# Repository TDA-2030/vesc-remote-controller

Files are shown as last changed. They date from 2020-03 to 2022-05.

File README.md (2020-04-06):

# VESC Remote Controller

This remote controller is used to control the VESC motor controller. It can easily control the electric skateboard equipped with VESC drive.

| Branch | Build Status |
| --- | --- |
| master | Build Status |
| dev | Build Status |

# Feature
- Low-power Consumption
- Support Remote Power Control
- Real-time Data Backhaul
- Show Real-time packet loss rate
- Battery Current Monitoring
- Input Voltage Range of 12 V to 60 V
- Two LED Headlights
- Reserved UART to Connect Modules such as GPS
- Acceleration Sensor MPU6050

# Repository Structure

- **transmitter**: Transmitter code
- **receiver**: Receiver code
- **image**: pcb or schematic
- **doc**: Documentation

# how to build

Transmitter you need to use IAR IDE to compile, while Receiver uses STM32 to compile with MDK-V5

# Hardware

## Transmitter model rendering

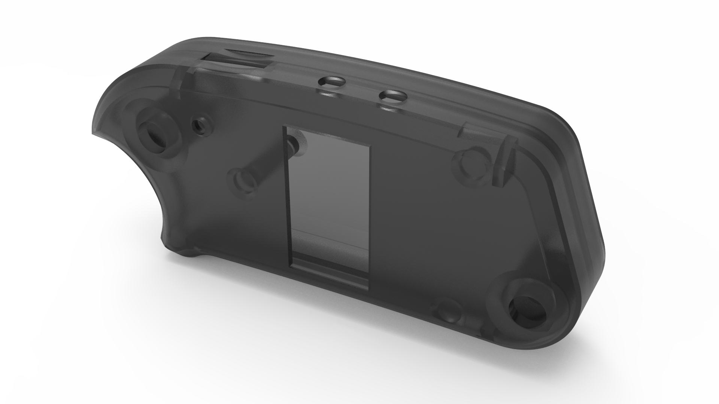
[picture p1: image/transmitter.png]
transmitter


## Receiver PCB

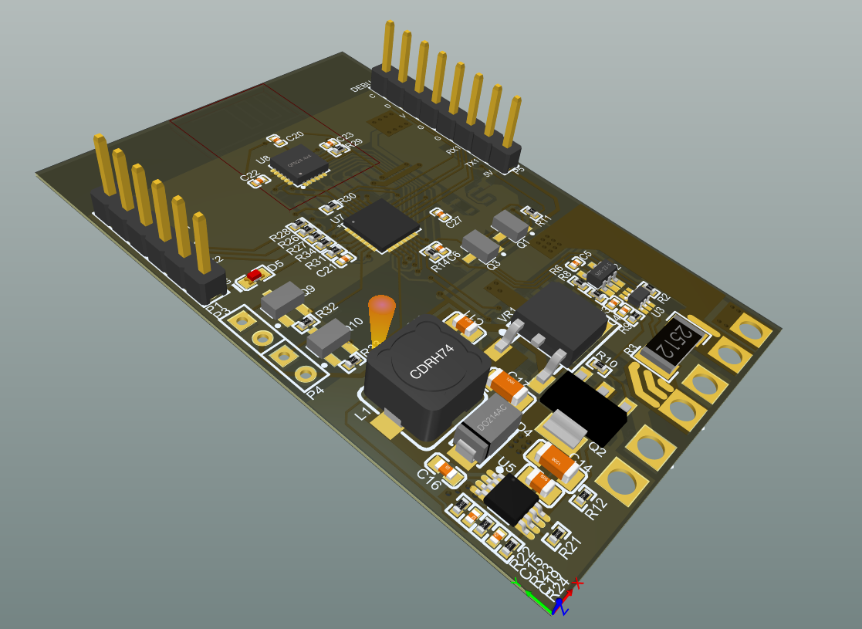
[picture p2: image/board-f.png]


## Schematic

PDF [doc/SCH-Transmitter.pdf](doc/SCH-Transmitter.pdf)

PDF [doc/SCH-Receiver.pdf](doc/SCH-Receiver.pdf)

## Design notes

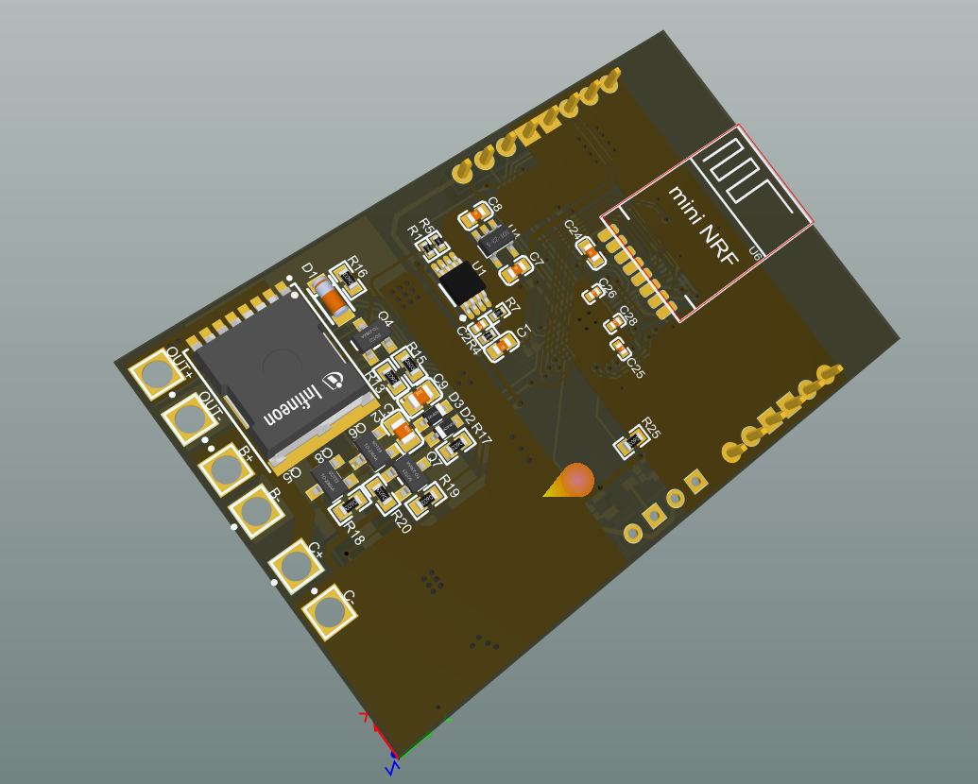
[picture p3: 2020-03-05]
image/board-b.png

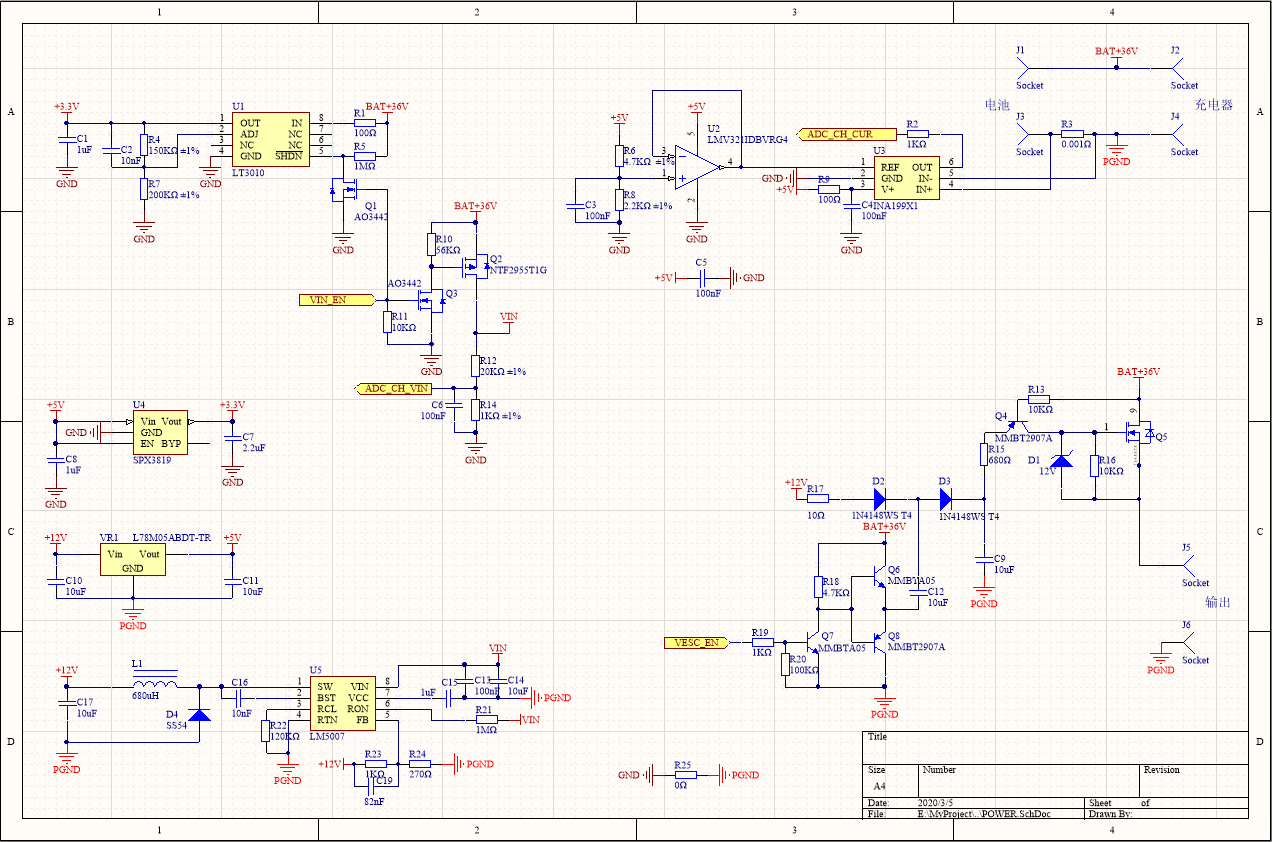
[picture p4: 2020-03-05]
image/sch-2.png

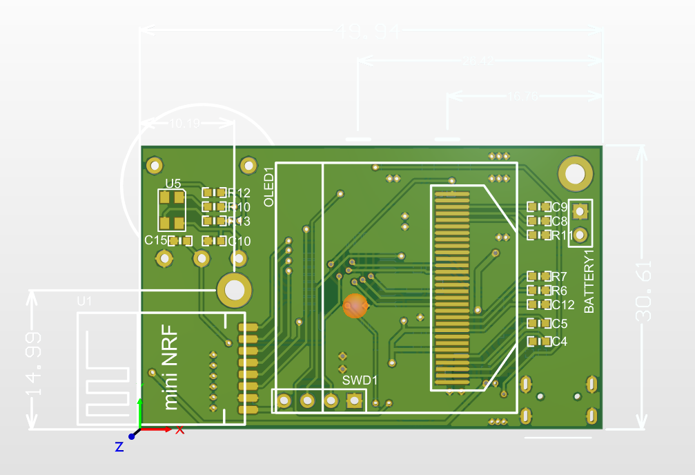
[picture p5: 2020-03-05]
image/transmitter-f.png

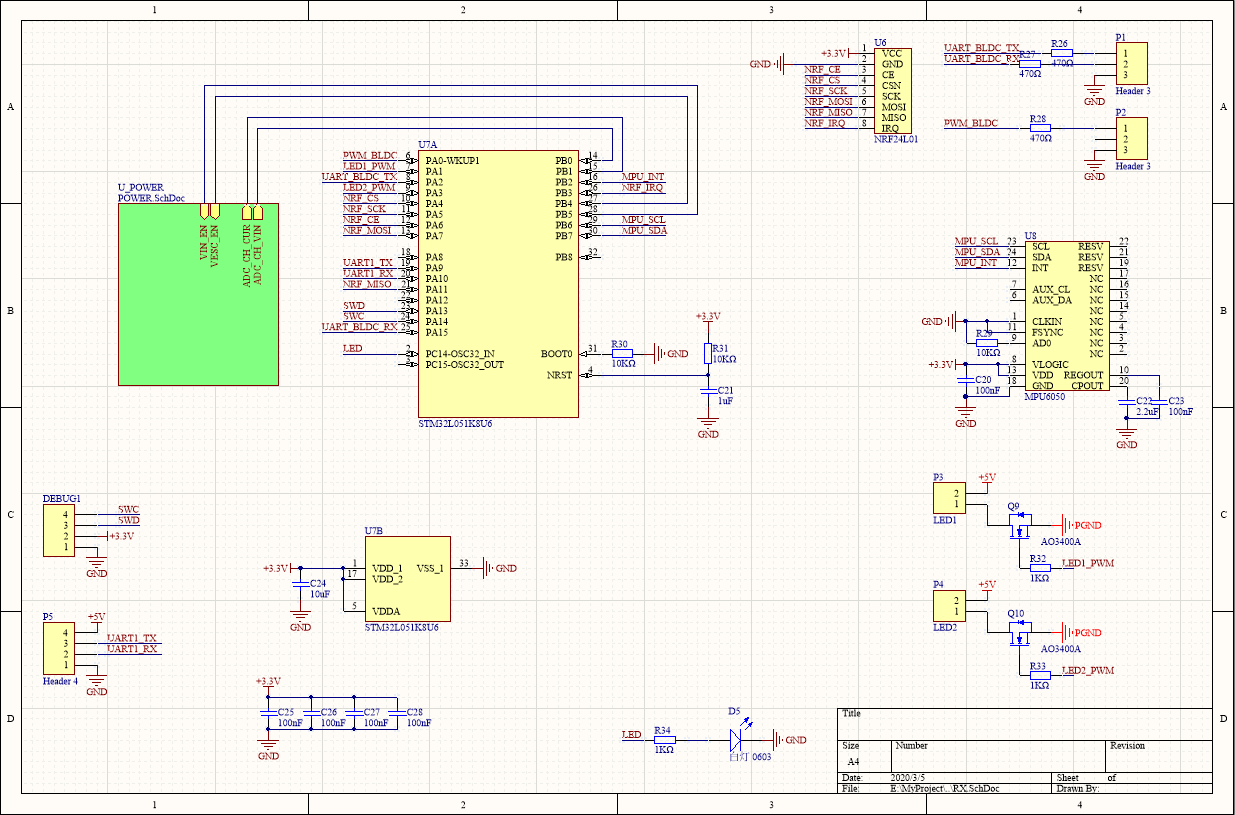
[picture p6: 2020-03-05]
image/sch-1.png

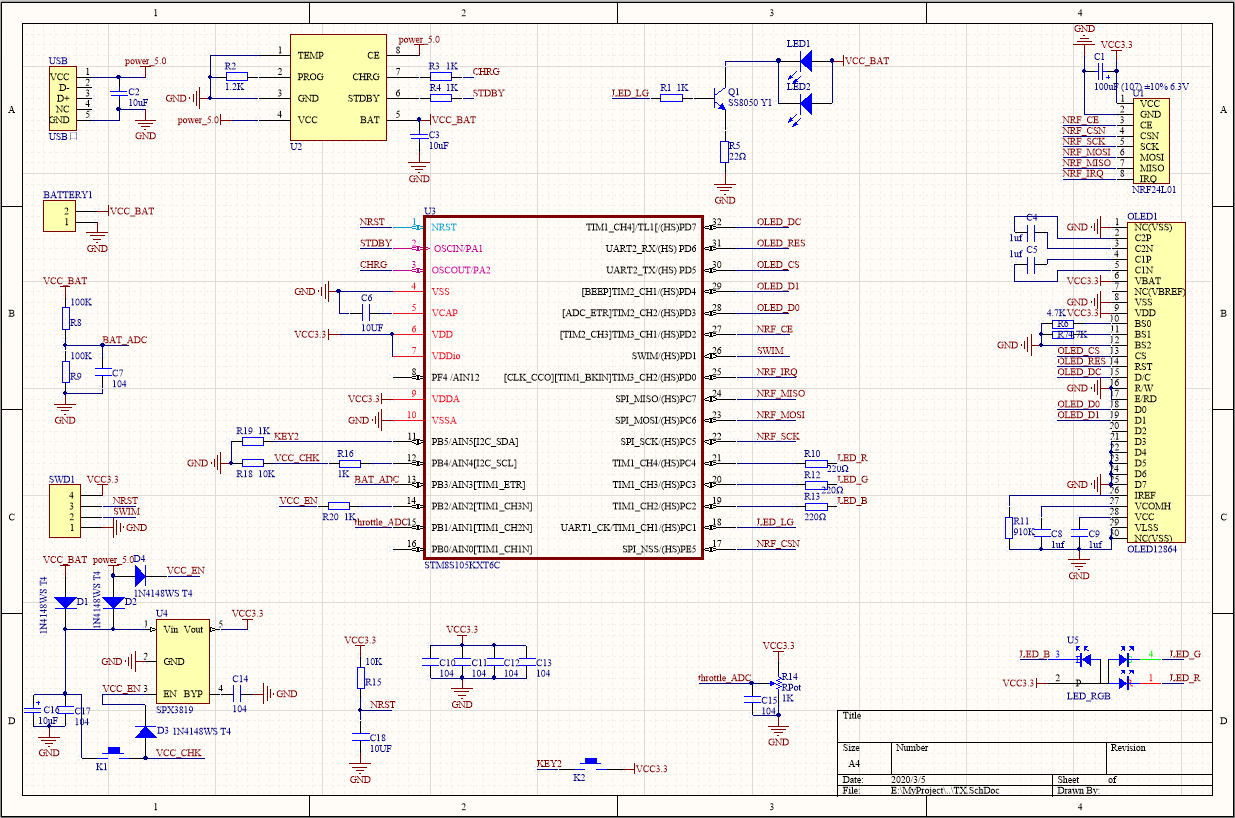
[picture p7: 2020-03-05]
image/sch-t.png

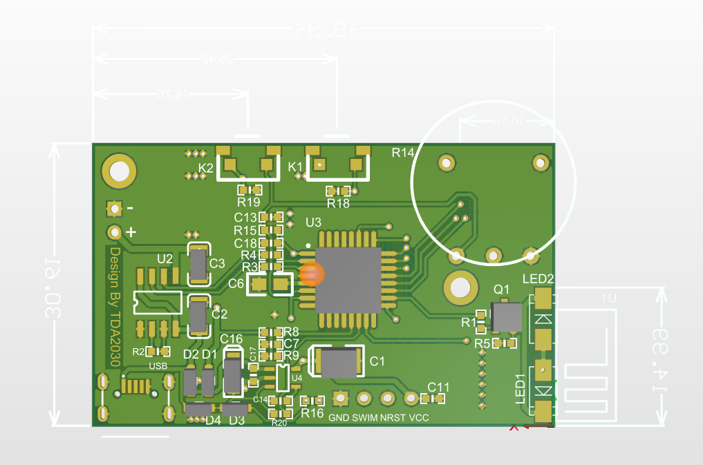
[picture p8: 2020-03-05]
image/transmitter-b.png

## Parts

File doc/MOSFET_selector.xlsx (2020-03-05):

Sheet: MOSFETs
Part Number | Status | Replacement Part | Package | Configuration | Polarity | ESD Diode | Schottky Diode | VDS (V) | VGS (±V) | ID (A) | PD (W) | RDS(ON) (mΩ max)† at VGS= |  |  |  |  |  | VGS(th) (max V) | Ciss (pF) | Coss (pF) | Crss (pF) | Qg* (nC) | Qgd (nC) | Td(on) (ns) | Td(off) (ns) | Trr (ns) | Qrr (nC)
 |  |  |  |  |  |  |  |  |  | 25°C | 25°C | 10V | 4.5V | 2.5V | 1.8V | 1.5V | 1.2V
AO3160 (http://aosmd.com/pdfs/datasheet/AO3160.pdf) | Full Production | AO3160E (http://aosmd.com/pdfs/datasheet/AO3160E.pdf) | SOT23A-3 | Single | N | No | No | 600 | 20 | 0.04 | 1.39 | 500000 | 600000 |  |  |  |  | 3.2 | 10 | 1.8 | 0.7 | 1* | 0.52 | 4 | 12.5 | 105 | 9.5 | * For bottom exposed packages, the Id and Pd are calculated at 100°C, otherwise calculated at 70°C.
AO3160E (http://aosmd.com/pdfs/datasheet/AO3160E.pdf) | Full Production |  | SOT23A-3 | Single | N | Yes | No | 600 | 20 | 0.04 | 1.39 | 500000 | 600000 |  |  |  |  | 3.2 | 9.5 | 1.7 | 0.6 | 0.9 | 0.49 |  |  | 105 | 9.5 | † Rds(on) measured at Vgs other than 10V, 4.5V, 1.8V, 1.5V, or 1.2V.
AO3162 (http://aosmd.com/pdfs/datasheet/AO3162.pdf) | Full Production |  | SOT23-3 | Single | N | No | No | 600 | 30 | 0.034 | 1.39 | 500000 |  |  |  |  |  | 4.1 | 4.2 | 0.45 | 0.05 | 0.7* | 0.05 | 13.8 | 39.2 | 105 | 9.5 | * Qg measured with Vgs at 10V. In all other cases Vgs at 4.5V.
AO3400 (http://aosmd.com/pdfs/datasheet/AO3400.pdf) | Not for New Designs | AOSS32334C (http://aosmd.com/pdfs/datasheet/AOSS32334C.pdf) | SOT23-3 | Single | N | No | No | 30 | 12 | 5.8 | 1.4 | 28 | 33 | 52 |  |  |  | 1.45 | 630 | 75 | 50 | 6 | 1.8 | 3 | 25 | 8.5 | 2.6
AO3400A (http://aosmd.com/pdfs/datasheet/AO3400A.pdf) | Not for New Designs | AOSS32334C (http://aosmd.com/pdfs/datasheet/AOSS32334C.pdf) | SOT23-3 | Single | N | No | No | 30 | 12 | 5.7 | 1.4 | 26.5 | 32 | 48 |  |  |  | 1.45 | 630 | 75 | 50 | 6 | 1.8 | 3 | 25 | 8.5 | 2.6
AO3401 (http://aosmd.com/pdfs/datasheet/AO3401.pdf) | Not for New Designs | AOSS21311C (http://aosmd.com/pdfs/datasheet/AOSS21311C.pdf) | SOT23-3 | Single | P | No | No | -30 | 12 | -4 | 1.4 | 50 | 60 | 85 |  |  |  | -1.3 | 645 | 80 | 55 | 7 | 2.5 | 6.5 | 41 | 11 | 3.5
AO3401A (http://aosmd.com/pdfs/datasheet/AO3401A.pdf) | Not for New Designs | AOSS21311C (http://aosmd.com/pdfs/datasheet/AOSS21311C.pdf) | SOT23-3 | Single | P | No | No | -30 | 12 | -4 | 1.4 | 50 | 60 | 85 |  |  |  | -1.3 | 645 | 80 | 55 | 7 | 2.5 | 6.5 | 41 | 11 | 3.5
AO3402 (http://aosmd.com/pdfs/datasheet/AO3402.pdf) | Not for New Designs | AOSS32338C (http://aosmd.com/pdfs/datasheet/AOSS32338C.pdf) | SOT23-3 | Single | N | No | No | 30 | 12 | 4 | 1.4 | 52 | 65 | 85 |  |  |  | 1.5 | 235 | 35 | 18 | 4.7 | 1.6 | 3.5 | 17.5 | 8.5 | 2.6
AO3403 (http://aosmd.com/pdfs/datasheet/AO3403.pdf) | Not for New Designs | AOSS21319C (http://aosmd.com/pdfs/datasheet/AOSS21319C.pdf) | SOT23-3 | Single | P | No | No | -30 | 12 | -2.6 | 1.4 | 115 | 150 | 200 |  |  |  | -1.4 | 260 | 37 | 20 | 2.8 | 1 | 6 | 20 | 11.5 | 4.5
AO3404 (http://aosmd.com/pdfs/datasheet/AO3404.pdf) | Obsolete |  | SOT23-3 | Single | N | No | No | 30 | 20 | 5 | 1.4 | 31 | 43 |  |  |  |  | 2.4 | 255 | 45 | 35 | 2.55 | 1.3 | 4.5 | 14.5 | 8.5 | 2.2
AO3404A (http://aosmd.com/pdfs/datasheet/AO3404A.pdf) | Not for New Designs | AOSS32334C (http://aosmd.com/pdfs/datasheet/AOSS32334C.pdf) | SOT23-3 | Single | N | No | No | 30 | 20 | 5.8 | 1.4 | 25 | 35 |  |  |  |  | 2.6 | 373 | 67 | 41 | 3.3 | 1.7 | 4.5 | 14.8 | 10.5 | 4.5
AO3406 (http://aosmd.com/pdfs/datasheet/AO3406.pdf) | Not for New Designs | AOSS32338C (http://aosmd.com/pdfs/datasheet/AOSS32338C.pdf) | SOT23-3 | Single | N | No | No | 30 | 20 | 3.6 | 1.4 | 50 | 70 |  |  |  |  | 2.5 | 170 | 35 | 23 | 2 | 1 | 4.5 | 18.5 | 7.5 | 2.5
AO3407 (http://aosmd.com/pdfs/datasheet/AO3407.pdf) | Not for New Designs | AOSS21311C (http://aosmd.com/pdfs/datasheet/AOSS21311C.pdf) | SOT23-3 | Single | P | No | No | -30 | 20 | -4.1 | 1.4 | 52 | 87 |  |  |  |  | -2.5 | 520 | 100 | 65 | 4.6 | 2.2 | 7.5 | 19 | 11 | 5.3
AO3407A (http://aosmd.com/pdfs/datasheet/AO3407A.pdf) | Not for New Designs | AOSS21311C (http://aosmd.com/pdfs/datasheet/AOSS21311C.pdf) | SOT23-3 | Single | P | No | No | -30 | 20 | -4.3 | 1.4 | 48 | 78 |  |  |  |  | -2.4 | 520 | 100 | 65 | 4.6 | 2.2 | 7.5 | 19 | 11 | 5.3
AO3409 (http://aosmd.com/pdfs/datasheet/AO3409.pdf) | Not for New Designs | AOSS21319C (http://aosmd.com/pdfs/datasheet/AOSS21319C.pdf) | SOT23-3 | Single | P | No | No | -30 | 20 | -2.6 | 1.4 | 110 | 180 |  |  |  |  | -2.4 | 197 | 42 | 26 | 2.2 | 1.1 | 7.5 | 11.8 | 11.3 | 4.4
AO3413 (http://aosmd.com/pdfs/datasheet/AO3413.pdf) | Full Production |  | SOT23-3 | Single | P | No | No | -20 | 8 | -3 | 1.4 |  | 80 | 100 | 130 |  |  | -1 | 560 | 80 | 70 | 8.5 | 2.1 | 7.2 | 53 | 37 | 27
AO3414 (http://aosmd.com/pdfs/datasheet/AO3414.pdf) | Not for New Designs | AOSS32338C (http://aosmd.com/pdfs/datasheet/AOSS32338C.pdf) | SOT23-3 | Single | N | No | No | 20 | 8 | 3 | 1.4 |  | 62 | 70 | 85 |  |  | 1 | 260 | 48 | 27 | 2.9 | 0.6 | 2.5 | 21 | 14 | 3.8
AO3415 (http://aosmd.com/pdfs/datasheet/AO3415.pdf) | Not for New Designs | AOSS21115C (http://aosmd.com/pdfs/datasheet/AOSS21115C.pdf) | SOT23-3 | Single | P | Yes | No | -20 | 8 | -4 | 1.5 |  | 41 | 53 | 65 |  |  | -0.9 | 751 | 115 | 80 | 9.3 | 2.2 | 13 | 19 | 26 | 51
AO3415A (http://www.aosmd.com/pdfs/datasheet/AO3415A.pdf) | Not for New Designs | AOSS21115C (http://aosmd.com/pdfs/datasheet/AOSS21115C.pdf) | SOT23-3 | Single | P | Yes | No | -20 | 8 | -5 | 1.5 |  | 41 | 53 | 65 |  |  | -0.9 | 751 | 115 | 80 | 9.3 | 2.2 | 13 | 19 | 26 | 51
AO3416 (http://aosmd.com/pdfs/datasheet/AO3416.pdf) | Not for New Designs | AOSS32136C (http://aosmd.com/pdfs/datasheet/AOSS32136C.pdf) | SOT23-3 | Single | N | Yes | No | 20 | 8 | 6.5 | 1.4 |  | 22 | 26 | 34 |  |  | 1.1 | 1295 | 160 | 87 | 10 | 2.6 | 280 | 3760 | 31 | 6.8
AO3418 (http://aosmd.com/pdfs/datasheet/AO3418.pdf) | Not for New Designs | AOSS32338C (http://aosmd.com/pdfs/datasheet/AOSS32338C.pdf) | SOT23-3 | Single | N | No | No | 30 | 12 | 3.8 | 1.4 | 55 | 65 | 85 |  |  |  | 1.5 | 235 | 35 | 18 | 4.7 | 1.6 | 3.5 | 17.5 | 8.5 | 2.6
AO3419 (http://aosmd.com/pdfs/datasheet/AO3419.pdf) | Full Production |  | SOT23-3 | Single | P | Yes | No | -20 | 12 | -3.5 | 1.4 | 85 | 102 | 140 |  |  |  | -1.2 | 325 | 63 | 37 | 3.1 | 1.1 | 11 | 8 | 11 | 4.3
AO3420 (http://aosmd.com/pdfs/datasheet/AO3420.pdf) | Not for New Designs | AOSS32136C (http://aosmd.com/pdfs/datasheet/AOSS32136C.pdf) | SOT23-3 | Single | N | No | No | 20 | 12 | 6 | 1.4 | 24 | 27 | 42 | 55 |  |  | 1.1 | 525 | 95 | 75 | 6 | 2 | 3 | 20 | 14 | 6
AO3421 (http://aosmd.com/pdfs/datasheet/AO3421.pdf) | Not for New Designs | AOSS21319C (http://aosmd.com/pdfs/datasheet/AOSS21319C.pdf) | SOT23-3 | Single | P | No | No | -30 | 20 | -2.6 | 1.4 | 110 | 180 |  |  |  |  | -2.4 | 197 | 42 | 26 | 2.2 | 1.1 | 7.5 | 11.8 | 11.3 | 4.4
AO3421E (http://aosmd.com/pdfs/datasheet/AO3421E.pdf) | Not for New Designs | AOSS21319C (http://aosmd.com/pdfs/datasheet/AOSS21319C.pdf) | SOT23-3 | Single | P | Yes | No | -30 | 20 | -3 | 1.4 | 95 | 160 |  |  |  |  | -2.5 | 215 | 46.5 | 27.5 | 2.2 | 1.2 | 8 | 13.5 | 9 | 16
AO3422 (http://aosmd.com/pdfs/datasheet/AO3422.pdf) | Not for New Designs |  | SOT23-3 | Single | N | No | No | 55 | 12 | 2.1 | 1.25 |  | 160 | 200 |  |  |  | 2 | 214 | 31 | 12.6 | 2.6 | 0.8 | 2.3 | 16.5 | 20 | 17
AO3423 (http://aosmd.com/pdfs/datasheet/AO3423.pdf) | Full Production |  | SOT23-3 | Single | P | Yes | No | -20 | 12 | -2 | 1.4 | 92 | 118 | 166 |  |  |  | -1.2 | 325 | 63 | 37 | 3.2 | 0.9 | 11 | 8 | 6.1 | 1.4
AO3424 (http://aosmd.com/pdfs/datasheet/AO3424.pdf) | Not for New Designs | AOSS32338C (http://aosmd.com/pdfs/datasheet/AOSS32338C.pdf) | SOT23-3 | Single | N | No | No | 30 | 12 | 3.8 | 1.4 | 55 | 65 | 85 |  |  |  | 1.5 | 235 | 35 | 18 | 4.7 | 1.6 | 3.5 | 17.5 | 8.5 | 2.6
AO3434A (http://aosmd.com/pdfs/datasheet/AO3434A.pdf) | Not for New Designs | AOSS32338C (http://aosmd.com/pdfs/datasheet/AOSS32338C.pdf) | SOT23-3 | Single | N | Yes | No | 30 | 12 | 4 | 1.4 | 52 | 60 | 78 |  |  |  | 1.5 | 245 | 35 | 20 | 2.6 | 1 | 2 | 22 | 6.5 | 7.5
AO3435 (http://aosmd.com/pdfs/datasheet/AO3435.pdf) | Not for New Designs | AOSS21115C (http://aosmd.com/pdfs/datasheet/AOSS21115C.pdf) | SOT23-3 | Single | P | No | No | -20 | 8 | -2.9 | 1 |  | 70 | 90 | 110 | 130 |  | -1 | 510 | 70 | 52 | 5.6 | 1.8 | 11 | 60 | 17 | 4
AO3442 (http://aosmd.com/pdfs/datasheet/AO3442.pdf) | Not for New Designs | AOSS62934 (http://aosmd.com/pdfs/datasheet/AOSS62934.pdf) | SOT23-3 | Single | N | No | No | 100 | 20 | 1 | 1.4 | 630 | 720 |  |  |  |  | 2.9 | 100 | 13 | 5 | 1.5 | 0.8 | 5 | 12 | 52 | 60
AO3451 (http://aosmd.com/pdfs/datasheet/AO3451.pdf) | Not for New Designs | AOSS21311C (http://aosmd.com/pdfs/datasheet/AOSS21311C.pdf) | SOT23-3 | Single | P | No | No | -30 | 12 | -4 | 1.4 | 50 | 60 | 85 |  |  |  | -1.3 | 645 | 80 | 55 | 7 | 2.5 |  |  | 11 | 3.5
AO3452 (http://aosmd.com/pdfs/datasheet/AO3452.pdf) | Not for New Designs | AOSS32338C (http://aosmd.com/pdfs/datasheet/AOSS32338C.pdf) | SOT23-3 | Single | N | No | No | 30 | 12 | 4 | 1.4 | 52 | 65 | 85 |  |  |  | 1.5 | 235 | 35 | 18 | 5 | 1.6 |  |  | 8.5 | 2.6
AO3453 (http://aosmd.com/pdfs/datasheet/AO3453.pdf) | Not for New Designs | AOSS21319C (http://aosmd.com/pdfs/datasheet/AOSS21319C.pdf) | SOT23-3 | Single | P | No | No | -30 | 12 | -2.6 | 1.4 | 115 | 150 | 200 |  |  |  | -1.4 | 260 | 37 | 20 | 3 | 1 |  |  | 11.5 | 4.5
AO3454 (http://aosmd.com/pdfs/datasheet/AO3454.pdf) | Not for New Designs | AOSS32334C (http://aosmd.com/pdfs/datasheet/AOSS32334C.pdf) | SOT23-3 | Single | N | No | No | 30 | 20 | 5.8 | 1.4 | 25 | 35 |  |  |  |  | 2.6 | 373 | 67 | 41 | 3.3 | 1.7 |  |  | 10.5 | 4.5
AO3456 (http://aosmd.com/pdfs/datasheet/AO3456.pdf) | Not for New Designs | AOSS32338C (http://aosmd.com/pdfs/datasheet/AOSS32338C.pdf) | SOT23-3 | Single | N | No | No | 30 | 20 | 3.6 | 1.4 | 50 | 70 |  |  |  |  | 2.5 | 200 | 35 | 23 | 2 | 1 |  |  | 7.5 | 2.5
AO3457 (http://aosmd.com/pdfs/datasheet/AO3457.pdf) | Not for New Designs | AOSS21311C (http://aosmd.com/pdfs/datasheet/AOSS21311C.pdf) | SOT23-3 | Single | P | No | No | 30 | 20 | -4.3 | 1.4 | 48 | 78 |  |  |  |  | -2.4 | 520 | 100 | 65 | 4.6 | 2.2 |  |  | 11 | 5.3
AO3459 (http://aosmd.com/pdfs/datasheet/AO3459.pdf) | Not for New Designs | AOSS21319C (http://aosmd.com/pdfs/datasheet/AOSS21319C.pdf) | SOT23-3 | Single | P | No | No | -30 | 20 | -2.6 | 1.4 | 110 | 180 |  |  |  |  | -2.4 | 197 | 42 | 26 | 2.2 | 1.1 |  |  | 11.3 | 4.4
AO3493 (http://aosmd.com/pdfs/datasheet/AO3493.pdf) | Not for New Designs | AOSS21115C (http://aosmd.com/pdfs/datasheet/AOSS21115C.pdf) | SOT23-3 | Single | P | No | No | -20 | 8 | -3 | 1.4 |  | 80 | 100 | 130 |  |  | -1 | 500 | 70 | 50 | 8.5 | 2.1 |  |  | 37 | 27
AO3494 (http://aosmd.com/pdfs/datasheet/AO3494.pdf) | Not for New Designs | AOSS32338C (http://aosmd.com/pdfs/datasheet/AOSS32338C.pdf) | SOT23-3 | Single | N | No | No | 20 | 8 | 3 | 1.4 |  | 62 | 70 | 85 |  |  | 1 | 260 | 48 | 27 | 3 | 0.6 |  |  | 14 | 3.8
AO3495 (http://aosmd.com/pdfs/datasheet/AO3495.pdf) | Not for New Designs | AOSS21115C (http://aosmd.com/pdfs/datasheet/AOSS21115C.pdf) | SOT23-3 | Single | P | Yes | No | -20 | 8 | -5 | 1.5 |  | 41 | 53 | 65 |  |  | -0.9 | 751 | 115 | 80 | 9.3 | 2.2 |  |  | 26 | 51
AO3498 (http://aosmd.com/pdfs/datasheet/AO3498.pdf) | Not for New Designs | AOSS32338C (http://aosmd.com/pdfs/datasheet/AOSS32338C.pdf) | SOT23-3 | Single | N | No | No | 30 | 12 | 3.8 | 1.4 | 55 | 65 | 85 |  |  |  | 1.5 | 235 | 35 | 18 | 5 | 1.6 |  |  | 8.5 | 2.6
AO3499 (http://aosmd.com/pdfs/datasheet/AO3499.pdf) | Full Production |  | SOT23-3 | Single | P | Yes | No | -20 | 12 | -3.5 | 1.4 | 85 | 102 | 140 |  |  |  | -1.2 | 325 | 63 | 37 | 3 | 1.1 |  |  | 11 | 4.3
AO4262E (http://www.aosmd.com/pdfs/datasheet/AO4262E.pdf) | Full Production |  | SO-8 | Single | N | Yes | No | 60 | 20 | 16.5 | 3.1 | 6.5 | 8.5 |  |  |  |  | 2.2 | 1650 | 520 | 52 | 15 | 6.5 | 8.5 | 50 | 19 | 60
AO4264E (http://www.aosmd.com/pdfs/datasheet/AO4264E.pdf) | Full Production |  | SO-8 | Single | N | Yes | No | 60 | 20 | 13.5 | 3.1 | 9.8 | 13.5 |  |  |  |  | 2.4 | 1100 | 300 | 28 | 7 | 3.5 | 8.5 | 50 | 18.5 | 59
AO4266E (http://www.aosmd.com/pdfs/datasheet/AO4266E.pdf) | Full Production |  | SO-8 | Single | N | No | No | 60 | 20 | 11 | 3.1 | 13.5 | 18 |  |  |  |  | 2.2 | 755 | 220 | 20 | 6.5 | 3 |  |  | 15 | 45
AO4268 (http://www.aosmd.com/res/data_sheets/AO4268.pdf) | Full Production |  | SO-8 | Single | N | No | No | 60 | 20 | 19 | 3.1 | 4.8 | 6.5 |  |  |  |  | 2.3 | 2500 | 670 | 65 | 21 | 6.5 | 6 | 22 | 22 | 80
AO4286 (http://www.aosmd.com/pdfs/datasheet/AO4286.pdf) | Full Production |  | SO-8 | Single | N | No | No | 100 | 20 | 4 | 2.5 | 68 | 92 |  |  |  |  | 2.9 | 390 | 30 | 3 | 2.8 | 1.2 | 6 | 18 | 15 | 53
AO4290A (http://www.aosmd.com/pdfs/datasheet/AO4290A.pdf) | Not for New Designs | AOSP66923 (http://www.aosmd.com/res/data_sheets/AOSP66923.pdf) | SO-8 | Single | N | No | No | 100 | 20 | 15.5 | 3.1 | 6.4 | 7.6 |  |  |  |  | 2.3 | 4525 | 345 | 22.5 | 30 | 9 |  |  | 32 | 162
AO4292E (http://www.aosmd.com/pdfs/datasheet/AO4292E.pdf) | Full Production |  | SO-8 | Single | N | Yes | No | 100 | 20 | 8 | 3.1 | 23 | 33 |  |  |  |  | 2.7 | 1200 | 93 | 6.3 | 8 | 2.5 | 7 | 20 | 20 | 80
AO4294 (http://www.aosmd.com/pdfs/datasheet/AO4294.pdf) | Not for New Designs | AOSP66923 (http://www.aosmd.com/res/data_sheets/AOSP66923.pdf) | SO-8 | Single | N | No | No | 100 | 20 | 11.5 | 3.1 | 12 | 15.5 |  |  |  |  | 2.4 | 2420 | 170 | 11 | 15 | 4 | 8 | 25 | 25 | 110
AO4294A (http://www.aosmd.com/pdfs/datasheet/AO4294A.pdf) | Not for New Designs | AOSP66923 (http://www.aosmd.com/res/data_sheets/AOSP66923.pdf) | SO-8 | Single | N | No | No | 100 | 20 | 11.5 | 3.1 | 12 | 15.5 |  |  |  |  | 2.5 | 2305 | 180 | 11.5 | 15.5 | 5 |  |  | 26.5 | 135
AO4296 (http://www.aosmd.com/pdfs/datasheet/AO4296.pdf) | Full Production | AOSP66920 (http://www.aosmd.com/res/data_sheets/AOSP66920.pdf) | SO-8 | Single | N | No | No | 100 | 20 | 13.5 | 3.1 | 8.3 | 10.6 |  |  |  |  | 2.3 | 3130 | 245 | 12.5 | 18.5 | 4.5 | 8 | 25 | 28 | 130
AO4306 (http://www.aosmd.com/pdfs/datasheet/AO4306.pdf) | Not for New Designs | AOSP36326C (http://www.aosmd.com/res/data_sheets/AOSP36326C.pdf) | SO-8 | Single | N | No | No | 30 | 20 | 13 | 3.1 | 11.5 | 15.5 |  |  |  |  | 2.5 | 760 | 125 | 70 | 6.6 | 3 | 4.4 | 17 | 7 | 8
AO4335 (http://www.aosmd.com/pdfs/datasheet/AO4335.pdf) | Not for New Designs | AOSP21321 (http://www.aosmd.com/res/data_sheets/AOSP21321.pdf) | SO-8 | Single | P | No | No | -30 | 25 | -10.5 | 3.1 | 18 | 36* |  |  |  |  | -3 | 1130 | 240 | 155 | 9.5 | 3.3 | 8.7 | 18 | 25 | 12
AO4354 (http://www.aosmd.com/pdfs/datasheet/AO4354.pdf) | Not for New Designs | AOSP32368 (http://www.aosmd.com/res/data_sheets/AOSP32368.pdf) | SO-8 | Single | N | No | No | 30 | 20 | 23 | 3.1 | 3.7 | 5.3 |  |  |  |  | 2.2 | 2010 | 898 | 124 | 17 | 8 | 7.5 | 37 | 14 | 20.3
AO4402 (http://www.aosmd.com/pdfs/datasheet/AO4402.pdf) | Not for New Designs | AO4402G (http://www.aosmd.com/res/data_sheets/AO4402G.pdf) | SO-8 | Single | N | No | No | 20 | 12 | 20 | 3.1 |  | 5.5 | 7 |  |  |  | 1.6 | 3860 | 740 | 580 | 36 | 12 | 7 | 70 | 17 | 36
AO4402G (http://www.aosmd.com/res/data_sheets/AO4402G.pdf) | Full Production |  | SO-8 | Single | N | No | No | 20 | 12 | 20 | 3.1 |  | 5.9 | 7.3 |  |  |  | 1.25 | 3300 | 485 | 370 | 31 | 8 |  |  | 17 | 30
AO4403 (http://aosmd.com/pdfs/datasheet/AO4403.pdf) | Not for New Designs | AOSP21311C (http://aosmd.com/pdfs/datasheet/AOSP21311C.pdf) | SO-8 | Single | P | No | No | -30 | 12 | -6 | 3.1 | 48 | 57 | 80 |  |  |  | -1.3 | 645 | 80 | 55 | 7 | 2.5 | 6.5 | 41 | 11 | 3.5
AO4404B (http://aosmd.com/pdfs/datasheet/AO4404B.pdf) | Not for New Designs | AOSP32320C (http://aosmd.com/pdfs/datasheet/AOSP32320C.pdf) | SO-8 | Single | N | No | No | 30 | 12 | 8.5 | 3.1 | 24 | 30 | 48 |  |  |  | 1.45 | 630 | 75 | 50 | 6 | 1.8 | 3 | 25 | 8.5 | 2.6
AO4405 (http://aosmd.com/pdfs/datasheet/AO4405.pdf) | Not for New Designs | AOSP21311C (http://aosmd.com/pdfs/datasheet/AOSP21311C.pdf) | SO-8 | Single | P | No | No | -30 | 20 | -6 | 3.1 | 50 | 85 |  |  |  |  | -2.4 | 520 | 100 | 65 | 4.6 | 2.2 | 7.5 | 19 | 11 | 5.3
AO4405E (http://aosmd.com/pdfs/datasheet/AO4405E.pdf) | Not for New Designs | AOSP21311C (http://aosmd.com/pdfs/datasheet/AOSP21311C.pdf) | SO-8 | Single | P | Yes | No | -30 | 20 | -6 | 2.5 | 45 | 80 |  |  |  |  | -1.5 | 495 | 100 | 56 | 4.2 | 2 |  |  | 9 | 13.5
AO4406A (http://aosmd.com/pdfs/datasheet/AO4406A.pdf) | Not for New Designs | AOSP36326C (http://aosmd.com/pdfs/datasheet/AOSP36326C.pdf) | SO-8 | Single | N | No | No | 30 | 20 | 13 | 3.1 | 11.5 | 15.5 |  |  |  |  | 2.5 | 760 | 125 | 70 | 6.6 | 3 | 4.4 | 17 | 7 | 8
AO4407 (http://aosmd.com/pdfs/datasheet/AO4407.pdf) | Obsolete | AOSP21307 (http://www.aosmd.com/res/data_sheets/AOSP21307.pdf) | SO-8 | Single | P | No | No | -30 | 25 | -12 | 3.1 | 14 | 30* |  |  |  |  | -2.8 | 2060 | 370 | 295 | 30* | 10 | 11 | 24 | 30 | 22
AO4407A (http://aosmd.com/pdfs/datasheet/AO4407A.pdf) | Not for New Designs | AOSP21307 (http://www.aosmd.com/res/data_sheets/AOSP21307.pdf) | SO-8 | Single | P | No | No | -30 | 25 | -12 | 3.1 | 13 | 17* |  |  |  |  | -3 | 2060 | 370 | 295 | 30* | 10 | 11 | 24 | 30 | 22
AO4411 (http://aosmd.com/pdfs/datasheet/AO4411.pdf) | Not for New Designs | AOSP21313C (http://www.aosmd.com/res/data_sheets/AOSP21313C.pdf) | SO-8 | Single | P | No | No | -30 | 20 | -8 | 3.1 | 32 | 55 |  |  |  |  | -2.4 | 760 | 140 | 95 | 6.7 | 3.2 | 8 | 17 | 15 | 9.7
AO4413 (http://aosmd.com/pdfs/datasheet/AO4413.pdf) | Obsolete | AOSP21357 (http://www.aosmd.com/res/data_sheets/AOSP21357.pdf) | SO-8 | Single | P | No | No | -30 | 25 | -15 | 3.1 | 8.5 |  |  |  |  |  | -3.5 | 2890 | 585 | 470 | 51* | 16 | 16 | 45 | 18 | 11
AO4419 (http://aosmd.com/pdfs/datasheet/AO4419.pdf) | Full Production |  | SO-8 | Single | P | No | No | -30 | 20 | -9.7 | 3.1 | 20 | 35 |  |  |  |  | -2.5 | 1040 | 180 | 125 | 9.6 | 4.6 | 10 | 26 | 11.5 | 25
AO4421 (http://aosmd.com/pdfs/datasheet/AO4421.pdf) | Full Production |  | SO-8 | Single | P | No | No | -60 | 20 | -6.2 | 3.1 | 40 | 50 |  |  |  |  | -3 | 2417 | 179 | 120 | 22.7 | 9.2 | 9.8 | 44 | 34 | 47
AO4423/L (http://aosmd.com/pdfs/datasheet/AO4423.pdf) | Obsolete | AOSP21357 (http://www.aosmd.com/res/data_sheets/AOSP21357.pdf) | SO-8 | Single | P | Yes | No | -30 | 25 | -17 | 3.1 | 7.2 |  |  |  |  |  | -2.6 | 2527 | 583 | 397 | 47* | 14 | 12 | 54 | 26.1 | 12.3
AO4425 (http://aosmd.com/pdfs/datasheet/AO4425.pdf) | Full Production |  | SO-8 | Single | P | Yes | No | -38 | 25 | -14 | 3.1 | 11 |  |  |  |  |  | -3.5 | 3800 | 560 | 350 | 63* | 16.1 | 12.4 | 97.5 | 35 | 33
AO4430 (http://aosmd.com/pdfs/datasheet/AO4430.pdf) | Not for New Designs | AOSP32368 (http://www.aosmd.com/res/data_sheets/AOSP32368.pdf) | SO-8 | Single | N | No | No | 30 | 20 | 18 | 3 | 5.5 | 7.5 |  |  |  |  | 2.5 | 6060 | 638 | 355 | 48 | 15 | 12 | 51.5 | 33.5 | 22
AO4435 (http://aosmd.com/pdfs/datasheet/AO4435.pdf) | Last Time Buy | AOSP21321 (http://www.aosmd.com/res/data_sheets/AOSP21321.pdf) | SO-8 | Single | P | No | No | -30 | 25 | -10.5 | 3.1 | 18 | 36 |  |  |  |  | -3 | 1130 | 240 | 155 | 9.5 | 3.3 | 8.7 | 18 | 25 | 12
AO4441 (http://aosmd.com/pdfs/datasheet/AO4441.pdf) | Full Production |  | SO-8 | Single | P | No | No | -60 | 20 | -4 | 3.1 | 100 | 130 |  |  |  |  | -3 | 930 | 85 | 35 | 8 | 3.2 | 8 | 31.5 | 27 | 32
AO4443 (http://aosmd.com/pdfs/datasheet/AO4443.pdf) | Full Production |  | SO-8 | Single | P | No | No | -40 | 20 | -6 | 3.1 | 42 | 63 |  |  |  |  | -2.6 | 940 | 97 | 72 | 8.4 | 4.3 | 10.3 | 39 | 17 | 11.5
AO4447A (http://aosmd.com/pdfs/datasheet/AO4447A.pdf) | Not for New Designs | AOSP21357 (http://www.aosmd.com/res/data_sheets/AOSP21357.pdf) | SO-8 | Single | P | Yes | No | -30 | 20 | -17 | 3.1 | 7 | 8 |  |  |  |  | -1.6 | 4580 | 755 | 564 | 41 | 17 | 180 | 1200 | 32 | 77
AO4449 (http://aosmd.com/pdfs/datasheet/AO4449.pdf) | Not for New Designs | AOSP21313C (http://www.aosmd.com/res/data_sheets/AOSP21313C.pdf) | SO-8 | Single | P | No | No | -30 | 20 | -7 | 3.1 | 34 | 54 |  |  |  |  | -2.4 | 760 | 140 | 95 | 6.7 | 3.2 | 8 | 17 | 15 | 9.7
AO4453 (http://www.aosmd.com/pdfs/datasheet/AO4453.pdf) | Full Production |  | SO-8 | Single | P | No | No | -12 | 8 | -9 | 2.5 |  | 19 | 26 | 36 | 50 |  | -0.9 | 1370 | 350 | 258 | 12.7 | 3.4 | 11 | 70 | 20.7 | 5.2
AO4455 (http://www.aosmd.com/pdfs/datasheet/AO4455.pdf) | Obsolete | AOSP21357 (http://www.aosmd.com/res/data_sheets/AOSP21357.pdf) | SO-8 | Single | P | No | No | -30 | 25 | -17 | 3.1 | 7.2 |  |  |  |  |  | -2.6 | 2823 | 574 | 424 | 54* | 16 | 12.5 | 49 | 22.3 | 8.8
AO4459 (http://aosmd.com/pdfs/datasheet/AO4459.pdf) | Not for New Designs | AOSP21311C (http://aosmd.com/pdfs/datasheet/AOSP21311C.pdf) | SO-8 | Single | P | No | No | -30 | 20 | -6.5 | 3.1 | 46 | 72 |  |  |  |  | -2.4 | 520 | 100 | 65 | 4.6 | 2.2 | 7.5 | 19 | 11 | 5.3
AO4466 (http://aosmd.com/pdfs/datasheet/AO4466.pdf) | Not for New Designs | AOSP32320C (http://aosmd.com/pdfs/datasheet/AOSP32320C.pdf) | SO-8 | Single | N | No | No | 30 | 20 | 10 | 3.1 | 23 | 35 |  |  |  |  | 2.6 | 373 | 67 | 41 | 3.5 | 1.6 | 4.3 | 15.8 | 6 | 6.6
AO4468 (http://aosmd.com/pdfs/datasheet/AO4468.pdf) | Not for New Designs | AOSP32320C (http://aosmd.com/pdfs/datasheet/AOSP32320C.pdf) | SO-8 | Single | N | No | No | 30 | 20 | 10.5 | 3.1 | 17 | 23 |  |  |  |  | 2.4 | 740 | 110 | 82 | 7.5 | 3 | 5 | 19 | 18 | 9
AO4476A (http://www.aosmd.com/pdfs/datasheet/AO4476A.pdf) | Not for New Designs | AOSP32314 (http://www.aosmd.com/res/data_sheets/AOSP32314.pdf) | SO-8 | Single | N | No | No | 30 | 20 | 15 | 3.1 | 7.7 | 10.8 |  |  |  |  | 2.5 | 1150 | 180 | 105 | 9.5 | 5 | 6.5 | 17 | 8.7 | 13.5
AO4480 (http://aosmd.com/pdfs/datasheet/AO4480.pdf) | Not for New Designs | AO4484 (http://www.aosmd.com/res/data_sheets/AO4484.pdf) | SO-8 | Single | N | Yes | No | 40 | 20 | 14 | 3.1 | 11.5 | 15.5 |  |  |  |  | 3 | 1600 | 320 | 100 | 10.5 | 4.8 | 3.5 | 13.2 | 31 | 33
AO4482 (http://www.aosmd.com/pdfs/datasheet/AO4482.pdf) | Full Production |  | SO-8 | Single | N | No | No | 100 | 20 | 6 | 3.1 | 37 | 42 |  |  |  |  | 2.7 | 1630 | 100 | 50 | 18 | 9 | 7 | 28 | 25 | 130
AO4484 (http://aosmd.com/pdfs/datasheet/AO4484.pdf) | Full Production |  | SO-8 | Single | N | No | No | 40 | 20 | 10 | 1.7 | 10 | 12.5 |  |  |  |  | 3 | 1500 | 215 | 135 | 13.6 | 6.4 | 6.4 | 29.6 | 30 | 19
AO4485 (http://aosmd.com/pdfs/datasheet/AO4485.pdf) | Full Production |  | SO-8 | Single | P | No | No | -40 | 20 | -10 | 1.7 | 15 | 20 |  |  |  |  | -2.5 | 2500 | 260 | 180 | 18.6 | 8.6 | 9.4 | 55 | 38 | 47
AO4486 (http://www.aosmd.com/pdfs/datasheet/AO4486.pdf) | Not for New Designs |  | SO-8 | Single | N | No | No | 100 | 20 | 4.2 | 3.1 | 79 | 90 |  |  |  |  | 2.7 | 778 | 55 | 24 | 8.1 | 4.1 | 6 | 21 | 21 | 94
AO4492 (http://www.aosmd.com/pdfs/datasheet/AO4492L.pdf) | Not for New Designs | AOSP32314 (http://www.aosmd.com/res/data_sheets/AOSP32314.pdf) | SO-8 | Single | N | No | No | 30 | 20 | 14 | 3.1 | 9.5 | 14 |  |  |  |  | 2.2 | 770 | 240 | 77 | 7.1 | 3.1 | 5 | 18 | 11 | 23
AO4494 (http://aosmd.com/pdfs/datasheet/AO4494.pdf) | Obsolete | AOSP32314 (http://www.aosmd.com/res/data_sheets/AOSP32314.pdf) | SO-8 | Single | N | No | No | 30 | 20 | 18 | 3.1 | 6.5 | 9.5 |  |  |  |  | 2.5 | 1590 | 240 | 145 | 15 | 7.8 | 6.7 | 22.5 | 28 | 24
AO4496 (http://aosmd.com/pdfs/datasheet/AO4496.pdf) | Not for New Designs | AOSP32320C (http://aosmd.com/pdfs/datasheet/AOSP32320C.pdf) | SO-8 | Single | N | No | No | 30 | 20 | 10 | 3.1 | 19.5 | 26 |  |  |  |  | 2.5 | 550 | 110 | 55 | 4.6 | 2.2 | 5 | 24 | 22 | 14
AO4498 (http://aosmd.com/pdfs/datasheet/AO4498.pdf) | Not for New Designs | AOSP32368 (http://www.aosmd.com/res/data_sheets/AOSP32368.pdf) | SO-8 | Single | N | No | No | 30 | 20 | 18 | 3.1 | 5.5 | 7.5 |  |  |  |  | 2.5 | 1910 | 316 | 227 | 18 | 11 | 8.1 | 29 | 14 | 40
AO4566 (http://aosmd.com/pdfs/datasheet/AO4566.pdf) | Not for New Designs | AOSP36326C (http://aosmd.com/pdfs/datasheet/AOSP36326C.pdf) | SO-8 | Single | N | No | No | 30 | 20 | 12 | 2.5 | 11 | 17 |  |  |  |  | 2.3 | 542 | 233 | 31 | 4.3 | 1.7 | 4 | 18 | 9.7 | 11.5
AO4576 (http://aosmd.com/pdfs/datasheet/AO4576.pdf) | Full Production |  | SO-8 | Single | N | No | No | 30 | 20 | 20 | 3.1 | 5.8 | 9.8 |  |  |  |  | 2.2 | 1037 | 441 | 61 | 6.8 | 3.6 | 5.5 | 18 | 12.7 | 17.2
AO4606 (http://aosmd.com/pdfs/datasheet/AO4606.pdf) | Full Production |  | SO-8 | Complementary | N | No | No | 30 | 20 | 6 | 2 | 30 | 42 |  |  |  |  | 2.4 | 255 | 45 | 35 | 2.55 | 1.3 | 4.5 | 14.5 | 8.5 | 2.2
AO4606 (http://aosmd.com/pdfs/datasheet/AO4606.pdf) | Full Production |  | SO-8 | Complementary | P | No | No | -30 | 20 | -6.5 | 2 | 28 | 44 |  |  |  |  | -2.4 | 760 | 140 | 95 | 6.7 | 3.2 | 8 | 17 | 15 | 9.7
AO4611 (http://aosmd.com/pdfs/datasheet/AO4611.pdf) | Not for New Designs |  | SO-8 | Complementary | N | No | No | 60 | 20 | 6.3 | 2 | 25 | 30 |  |  |  |  | 3 | 1920 | 155 | 116 | 24.2 | 14.4 | 7.6 | 28.9 | 33.2 | 43
AO4611 (http://aosmd.com/pdfs/datasheet/AO4611.pdf) | Not for New Designs |  | SO-8 | Complementary | P | No | No | -60 | 20 | -4.9 | 2 | 42 | 52 |  |  |  |  | -3 | 2417 | 179 | 120 | 22.8 | 9.6 | 9.8 | 44 | 32 | 42
AO4612 (http://aosmd.com/pdfs/datasheet/AO4612.pdf) | Full Production |  | SO-8 | Complementary | N | No | No | 60 | 20 | 4.5 | 2 | 56 | 77 |  |  |  |  | 3 | 450 | 60 | 25 | 4.3 | 2.2 | 4.7 | 15.7 | 27.5 | 32
AO4612 (http://aosmd.com/pdfs/datasheet/AO4612.pdf) | Full Production |  | SO-8 | Complementary | P | No | No | -60 | 20 | -3.2 | 2 | 105 | 135 |  |  |  |  | -3 | 930 | 85 | 35 | 8 | 3.2 | 8 | 31.5 | 27 | 32
AO4614B (http://aosmd.com/pdfs/datasheet/AO4614B.pdf) | Full Production |  | SO-8 | Complementary | N | No | No | 40 | 20 | 6 | 2 | 30 | 38 |  |  |  |  | 3 | 516 | 82 | 43 | 4.3 | 1.4 | 6.4 | 16.2 | 18 | 10
AO4614B (http://aosmd.com/pdfs/datasheet/AO4614B.pdf) | Full Production |  | SO-8 | Complementary | P | No | No | -40 | 20 | -5 | 2 | 45 | 63 |  |  |  |  | -3 | 940 | 97 | 72 | 7.9 | 3.2 | 6.2 | 44.8 | 21 | 14
AO4616 (http://aosmd.com/pdfs/datasheet/AO4616.pdf) | Full Production |  | SO-8 | Complementary | N | No | No | 30 | 20 | 8.5 | 2 | 20 | 28 |  |  |  |  | 2.4 | 740 | 110 | 82 | 7.5 | 3 | 5 | 19 | 8 | 18
AO4616 (http://aosmd.com/pdfs/datasheet/AO4616.pdf) | Full Production |  | SO-8 | Complementary | P | No | No | -30 | 20 | -7 | 2 | 22 | 40 |  |  |  |  | -2.5 | 1040 | 180 | 125 | 9.6 | 4.6 | 10 | 25 | 11.5 | 25
AO4620 (http://aosmd.com/pdfs/datasheet/AO4620.pdf) | Full Production |  | SO-8 | Complementary | N | No | No | 30 | 20 | 7.2 | 2 | 24 | 36 |  |  |  |  | 2.6 | 373 | 67 | 41 | 3.5 | 1.7 | 4.5 | 14.9 | 10.5 | 4.5
AO4620 (http://aosmd.com/pdfs/datasheet/AO4620.pdf) | Full Production |  | SO-8 | Complementary | P | No | No | -30 | 20 | -5.3 | 2 | 32 | 55 |  |  |  |  | -2.4 | 760 | 140 | 95 | 6.7 | 3.2 | 8 | 17 | 15 | 9.7
AO4627 (http://aosmd.com/pdfs/datasheet/AO4627.pdf) | Full Production |  | SO-8 | Complementary | N | No | No | 30 | 20 | 4.5 | 2 | 50 | 68 |  |  |  |  | 2.5 | 170 | 35 | 23 | 2 | 1 | 4.5 | 18.5 | 7.5 | 2.5
AO4627 (http://aosmd.com/pdfs/datasheet/AO4627.pdf) | Full Production |  | SO-8 | Complementary | P | No | No | -30 | 20 | -3.5 | 2 | 100 | 165 |  |  |  |  | -2.4 | 197 | 42 | 26 | 2.2 | 1.1 | 7.5 | 11.8 | 11.3 | 4.4
AO4629 (http://www.aosmd.com/pdfs/datasheet/AO4629.pdf) | Full Production |  | SO-8 | Complementary | N | No | No | 30 | 20 | 6 | 2 | 30 | 42 |  |  |  |  | 2.4 | 250 | 45 | 35 | 2.55 | 1.3 | 4.5 | 14.5 | 8.5 | 2.2
AO4629 (http://www.aosmd.com/pdfs/datasheet/AO4629.pdf) | Full Production |  | SO-8 | Complementary | P | No | No | -30 | 20 | -5.5 | 2 | 41 | 74 |  |  |  |  | -2.5 | 520 | 100 | 65 | 4.6 | 2.2 | 7.5 | 19 | 11 | 5.3
AO4630 (http://www.aosmd.com/pdfs/datasheet/AO4630.pdf) | Full Production |  | SO-8 | Complementary | N | No | No | 30 | 12 | 7 | 2 | 23 | 28 | 36 |  |  |  | 1.45 | 670 | 75 | 45 | 6 | 1.8 | 4.5 | 14.5 | 6.5 | 7.5
AO4630 (http://www.aosmd.com/pdfs/datasheet/AO4630.pdf) | Full Production |  | SO-8 | Complementary | P | No | No | -30 | 12 | -5 | 2 | 48 | 57 | 78 |  |  |  | -1.3 | 700 | 80 | 60 | 7 | 2.5 |  |  | 15 | 40
AO4752 (http://www.aosmd.com/pdfs/datasheet/AO4752.pdf) | Not for New Designs | AOSP36326C (http://www.aosmd.com/res/data_sheets/AOSP36326C.pdf) | SO-8 | Single | N | No | Yes | 30 | 20 | 15 | 3.1 | 8.8 | 15.5 |  |  |  |  | 2.5 | 605 | 275 | 36.5 | 5.5 | 2.6 | 5 | 17 | 11.5 | 12.5
AO4800 (http://aosmd.com/pdfs/datasheet/AO4800.pdf) | Not for New Designs | AOSD32334C (http://aosmd.com/pdfs/datasheet/AOSD32334C.pdf) | SO-8 | Dual | N | No | No | 30 | 12 | 6.9 | 2 | 27 | 32 | 50 |  |  |  | 1.5 | 630 | 75 | 50 | 6 | 1.8 | 3 | 25 | 8.5 | 2.6
AO4800B (http://aosmd.com/pdfs/datasheet/AO4800B.pdf) | Not for New Designs | AOSD32334C (http://aosmd.com/pdfs/datasheet/AOSD32334C.pdf) | SO-8 | Dual | N | No | No | 30 | 12 | 6.9 | 2 | 27 | 32 | 50 |  |  |  | 1.5 | 630 | 75 | 50 | 6 | 1.8 | 3 | 25 | 8.5 | 2.6
AO4801 (http://aosmd.com/pdfs/datasheet/AO4801.pdf) | Not for New Designs | AOSD21311C (http://aosmd.com/pdfs/datasheet/AOSD21311C.pdf) | SO-8 | Dual | P | No | No | -30 | 12 | -5 | 2 | 48 | 57 | 80 |  |  |  | -1.3 | 645 | 80 | 55 | 7 | 2.5 | 6.5 | 41 | 11 | 3.5
AO4801A (http://aosmd.com/pdfs/datasheet/AO4801A.pdf) | Not for New Designs | AOSD21311C (http://aosmd.com/pdfs/datasheet/AOSD21311C.pdf) | SO-8 | Dual | P | No | No | -30 | 12 | -5 | 2 | 48 | 57 | 80 |  |  |  | -1.3 | 645 | 80 | 55 | 7 | 2.5 | 6.5 | 41 | 11 | 3.5
AO4803 (http://aosmd.com/pdfs/datasheet/AO4803.pdf) | Not for New Designs | AOSD21311C (http://aosmd.com/pdfs/datasheet/AOSD21311C.pdf) | SO-8 | Dual | P | No | No | -30 | 20 | -5 | 2 | 52 | 87 |  |  |  |  | -2.4 | 520 | 100 | 65 | 4.6 | 2.2 | 7.5 | 19 | 11 | 5.3
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

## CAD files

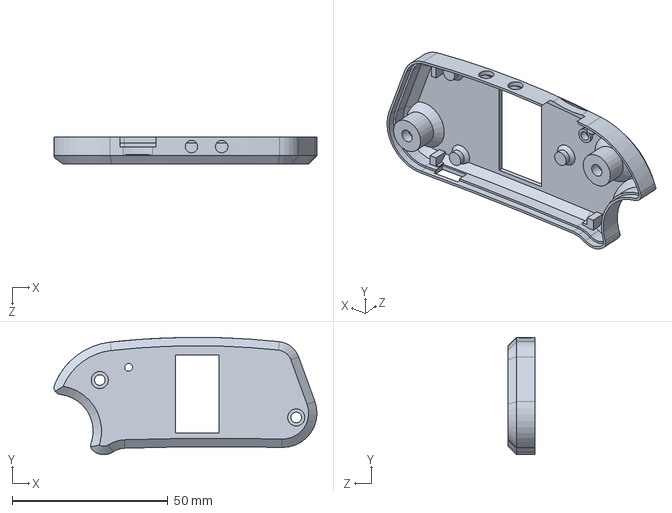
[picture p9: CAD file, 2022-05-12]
3d-models/遥控器前壳.SLDPRT
84.4 x 37.6 x 8.70 mm

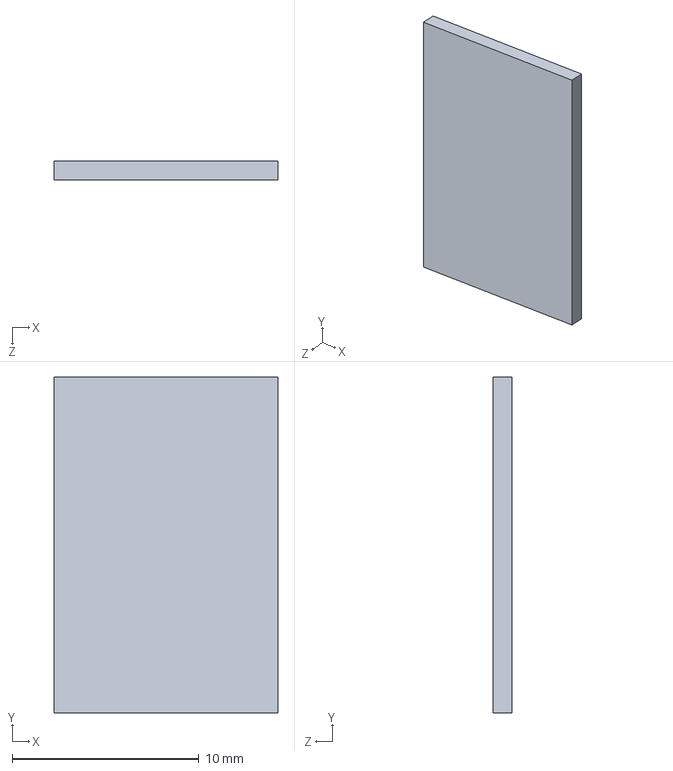
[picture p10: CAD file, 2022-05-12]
mininrf/零件1.STEP
12.0 x 18.0 x 1.00 mm

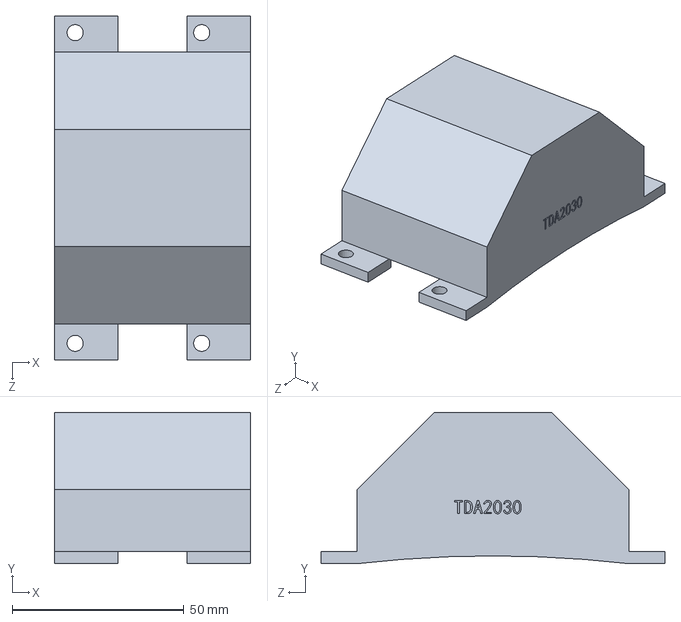
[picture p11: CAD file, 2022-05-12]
3d-models/bjm.SLDPRT
57.0 x 44.0 x 100.0 mm

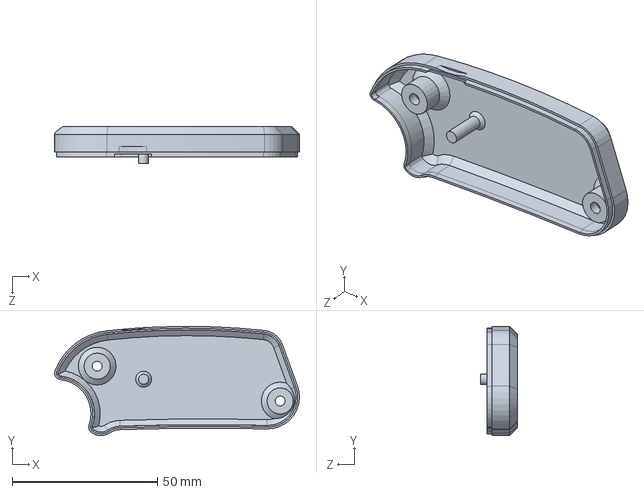
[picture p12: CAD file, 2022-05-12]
3d-models/遥控器后壳.SLDPRT
84.4 x 37.6 x 12.7 mm

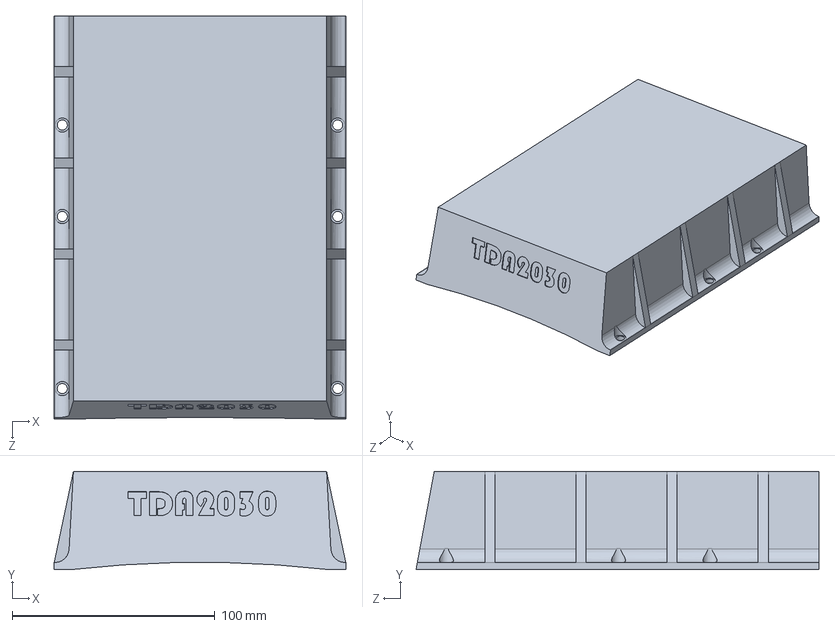
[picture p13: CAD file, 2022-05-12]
3d-models/电池盒.SLDPRT
144.0 x 48.5 x 199.0 mm

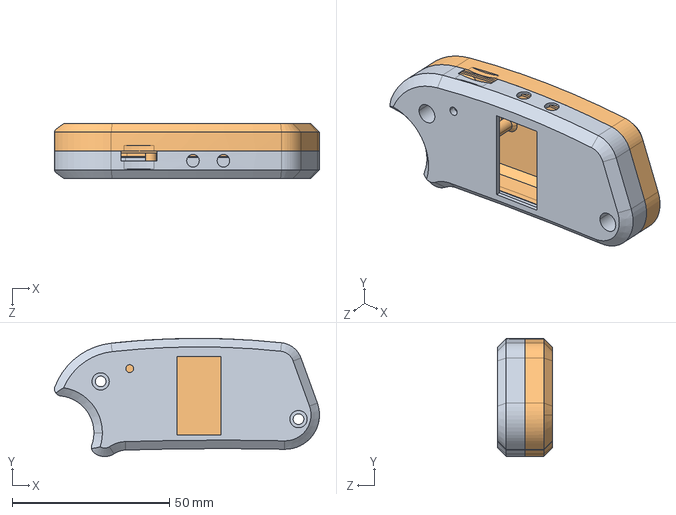
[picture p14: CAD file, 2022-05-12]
3d-models/装配体1.STEP
84.4 x 37.6 x 17.4 mm
猀諷んヶ褲
遥控器后壳

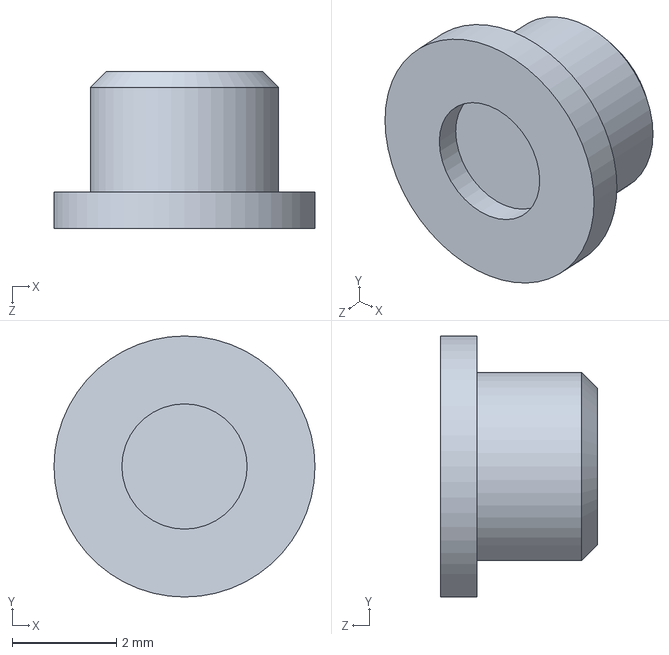
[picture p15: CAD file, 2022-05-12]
3d-models/遥控器按钮.SLDPRT
5.00 x 5.00 x 3.00 mm

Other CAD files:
mininrf/2.NRF24L01程序/NRF24L01程序/双按键测试程序/out/MAIN.obj
mininrf/2.NRF24L01程序/NRF24L01程序/双按键测试程序/out/delay.obj
mininrf/2.NRF24L01程序/NRF24L01程序/双按键测试程序/out/UART.obj
mininrf/2.NRF24L01程序/NRF24L01程序/双按键测试程序/out/nrf24l01p.obj
3d-models/装配体1.SLDASM
mininrf/零件1.SLDPRT

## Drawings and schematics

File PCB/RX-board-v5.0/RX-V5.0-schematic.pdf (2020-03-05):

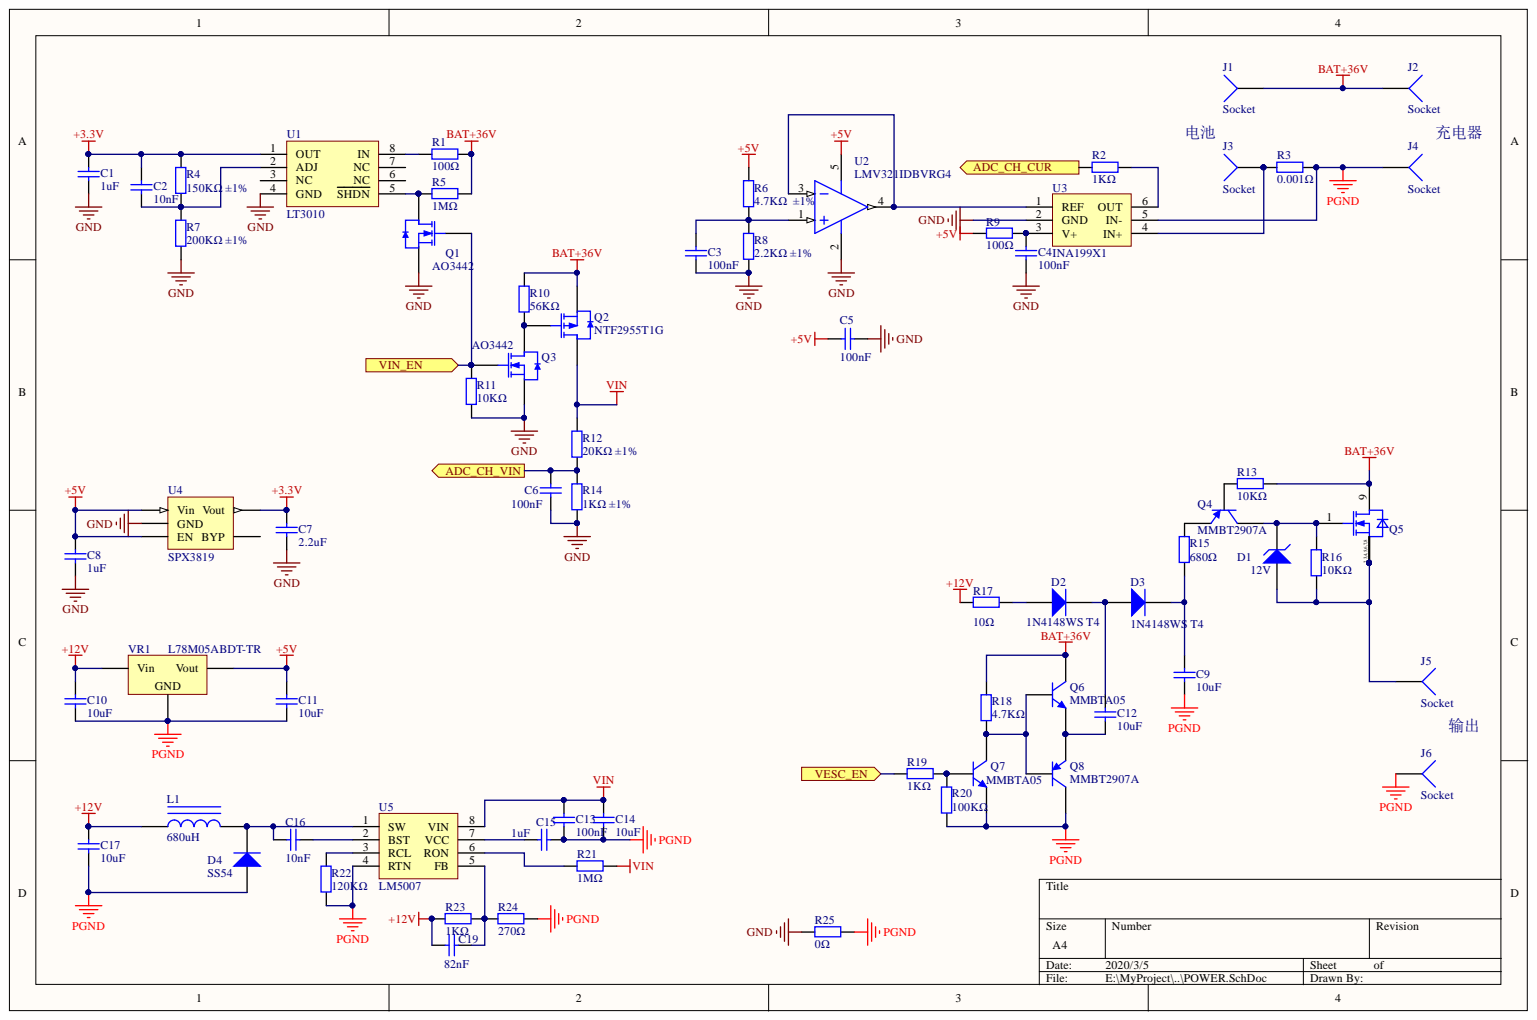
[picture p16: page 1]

C13
100nF

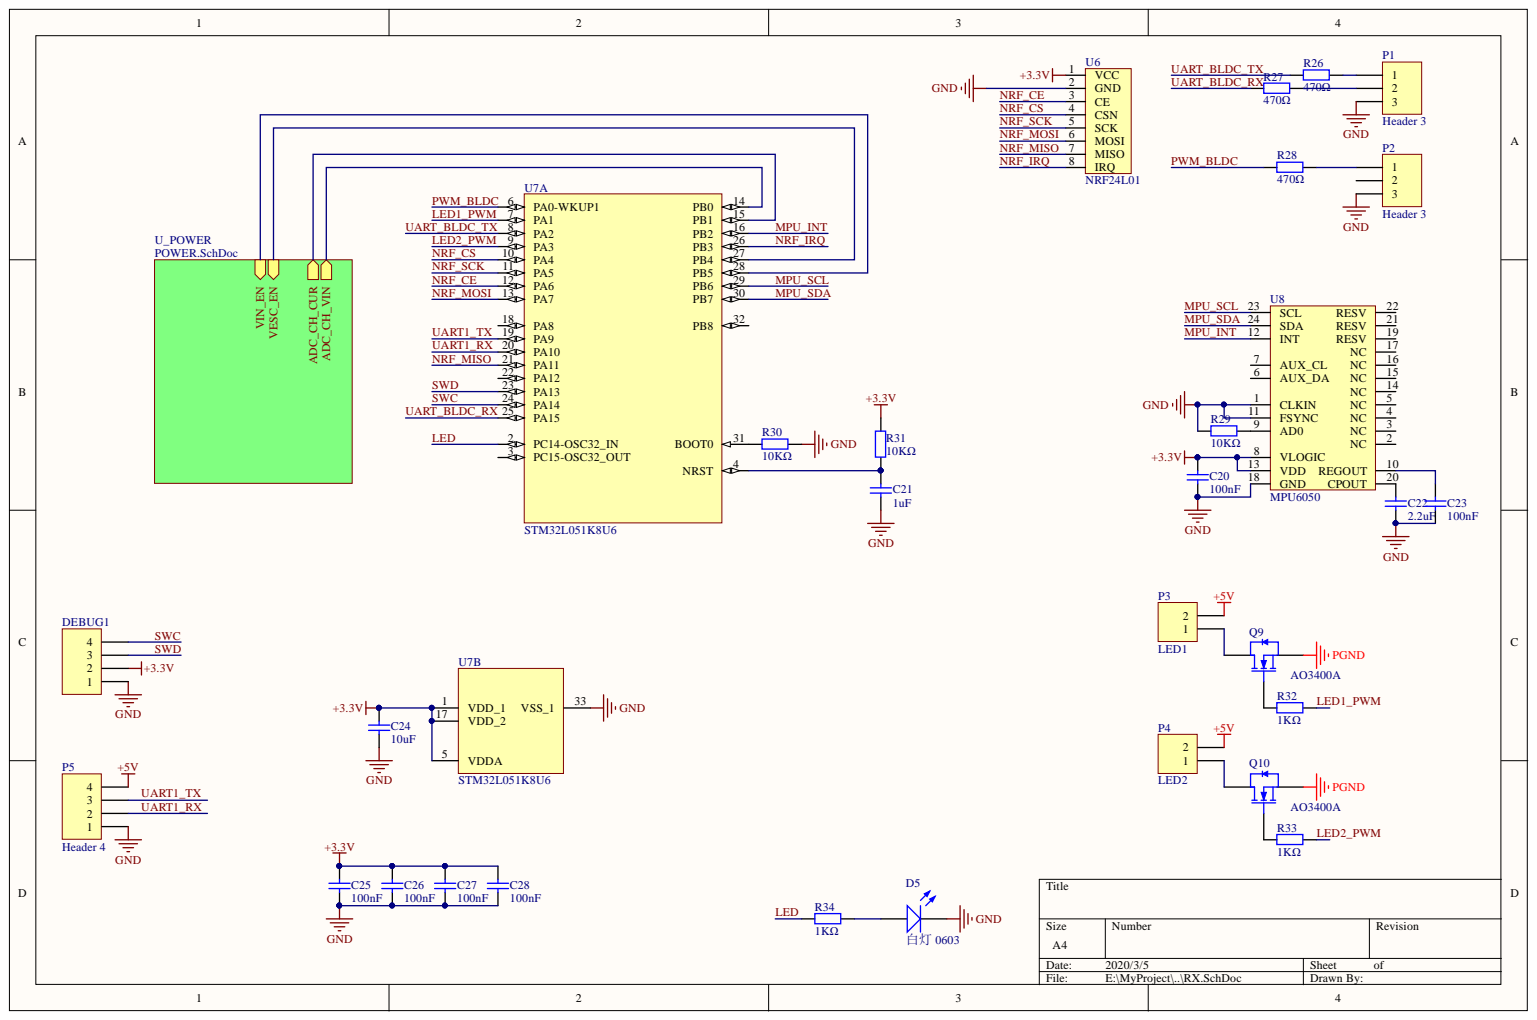
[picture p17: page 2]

NRF_CE 1 2 | PA 5 PB5 PA 6 PB6 PA 7 PB7 PA 8 PB8 PA 9 PA 1 0 PA 1 1 PA 1 2 PA 1 3 PA 1 4 PA 1 5 PC1 4-OSC3 2 _IN BO O T 0 PC1 5-OSC3 2 _ O U T NRST

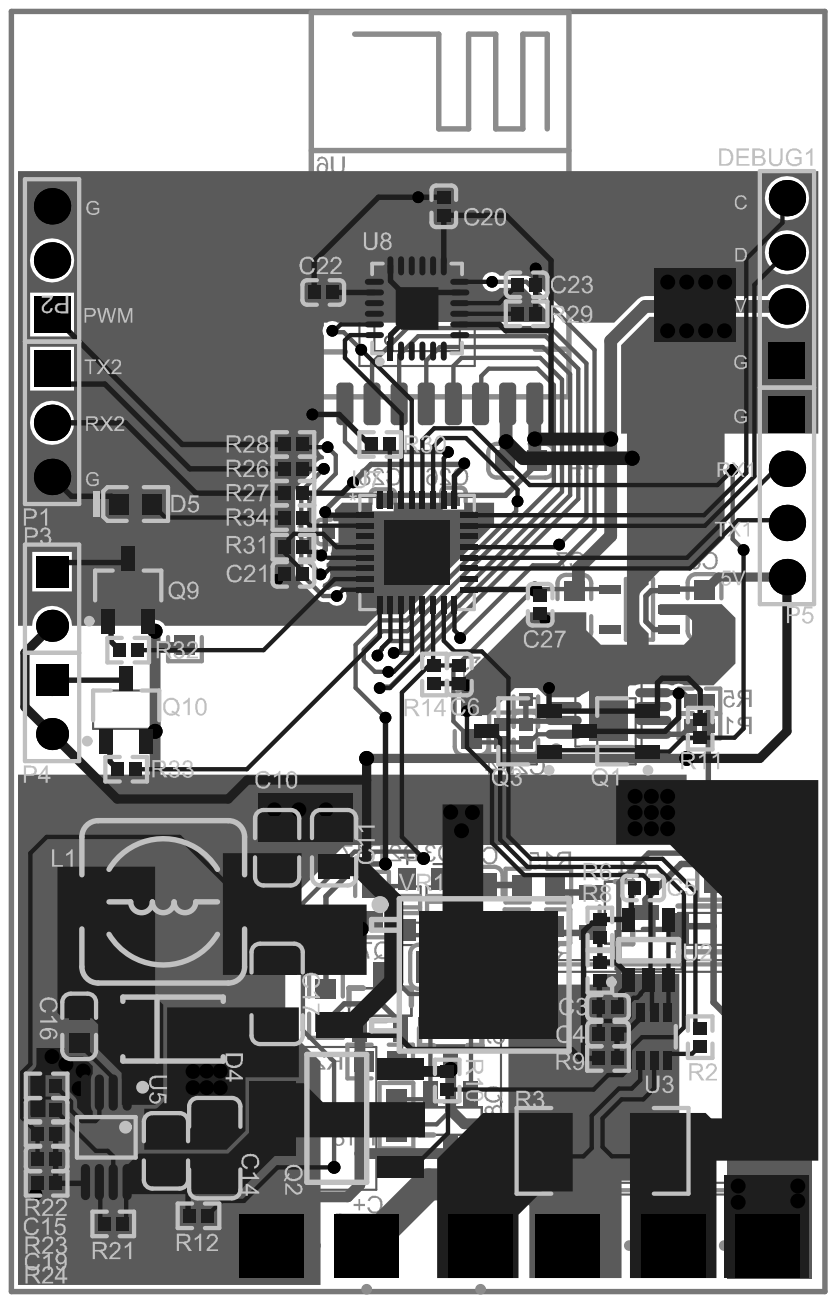
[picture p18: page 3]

# Board Stack Report

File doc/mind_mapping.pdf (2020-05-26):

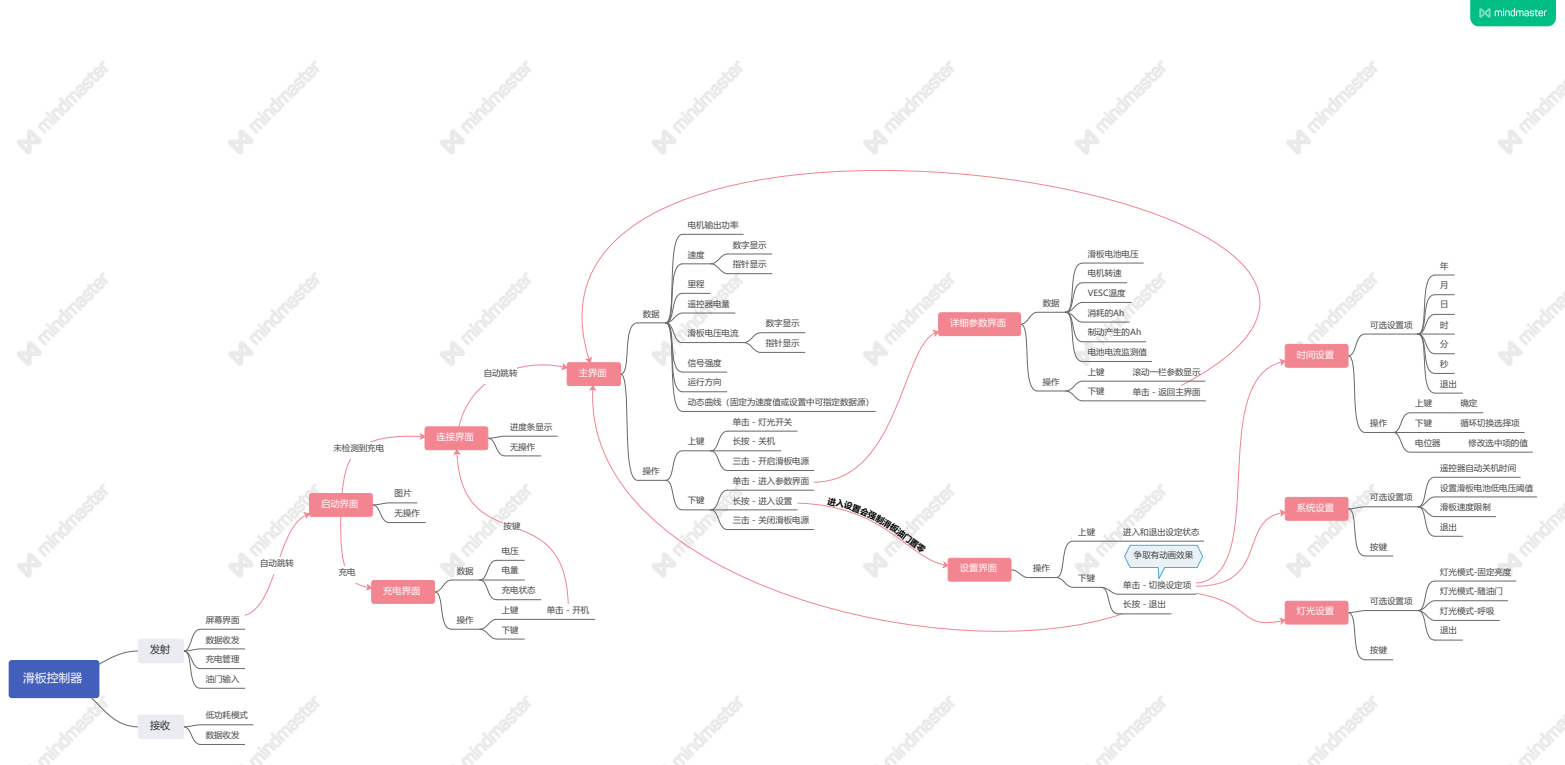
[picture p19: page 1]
自动跳转; 未检测到充电; 进入设置会强制滑板油门置零; 争取有动画效果; 滑板控制器; 屏幕界面; 数据收发; 充电管理; 油门输入; 低功耗模式; 主界面; 充电界面; 启动界面; 连接界面; 详细参数界面; 设置界面; 遥控器电量; 滑板电压电流; 信号强度; 单击 - 灯光开关; 单击 - 进入参数界面; 长按 - 进入设置; 充电状态; 进度条显示; 滑板电池电压; 电机输出功率; 电机转速; VESC温度; 运行方向; 三击 - 开启滑板电源; 无操作; 消耗的Ah; 制动产生的Ah; 电池电流监测值; 单击 - 返回主界面; 单击 - 切换设定项; 进入和退出设定状态; 时间设置; 系统设置; 灯光设置; 年月日时分秒; 遥控器自动关机时间; 灯光模式; -固定亮度; -随油门; 设置滑板电池低电压阈值; 数字显示; 指针显示; 可选设置项; 循环切换选择项; 滚动一栏参数显示; 动态曲线（固定为速度值或设置中可指定数据源）; 电位器; 修改选中项的值; 滑板速度限制

三击 - 关闭滑板电源 无操作

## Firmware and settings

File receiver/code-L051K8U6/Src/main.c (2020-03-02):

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

/* Includes ------------------------------------------------------------------*/
#include "main.h"
#include "adc.h"
#include "dma.h"
#include "i2c.h"
#include "rtc.h"
#include "spi.h"
#include "tim.h"
#include "usart.h"
#include "gpio.h"

/* USER CODE BEGIN Includes */
#include "comm_uart.h"
#include "bldc_interface.h"

#include "24l01.h"
#include "control.h"

#include "stmflash.h"

/* USER CODE END Includes */

/* USER CODE BEGIN PM */
#define SETTINGS_ADDR DATA_EEPROM_BASE
#define FLASH_CHECK (0x12345678)   //检验值
/* USER CODE END PM */


void SystemClock_Config(void);
/* USER CODE BEGIN 0 */

Setting_TypeDef setting={0};
sample_TypeDef SampleData={0};
System_TypeDef system={0};


//延时nus
//nus为要延时的us数.		    								   
void delay_us(uint32_t nus)
{		
	uint32_t t;
	while(nus--)
	{
		t=2;
		while(t--){}
		
	}
}


/** 
* @brief  : systick中断回调函数，1ms调用一次
* @param  : 
* @param  : 
* @return : 
*/
void HAL_SYSTICK_Callback(void)
{
	bldc_packet_timer();
	
}

/**
  * @brief  Wake Up Timer callback.
  * @param  hrtc RTC handle
  * @retval None
  */
void HAL_RTCEx_WakeUpTimerEventCallback(RTC_HandleTypeDef *hrtc)
{
	
}

/**
  * @brief  Conversion complete callback in non-blocking mode.
  * @param  hadc ADC handle
  * @retval None
  */
void HAL_ADC_ConvCpltCallback(ADC_HandleTypeDef* hadc)
{
	
}



//系统进入待机模式
void Sys_Enter_Standby(void)
{			 
	
	RF24L01_Set_Mode(MODE_PD);//设置为掉电模式
	LL_GPIO_ResetOutputPin(IO_VIN_EN_GPIO_Port, IO_VIN_EN_Pin);
//	hal_gpio_;	//复位所有IO口	
//	RCC_APB1PeriphClockCmd(RCC_APB1Periph_PWR, ENABLE);	//使能PWR外设时钟
	HAL_PWREx_EnableUltraLowPower();
	HAL_PWR_EnterSTOPMode(PWR_LOWPOWERREGULATOR_ON, PWR_STOPENTRY_WFI);	 
}

#define ROUND_UP(x, align) (((int) (x) + (align - 1)) & ~(align - 1))
/** 
* @brief  : flash参数读取
* @param  : 
* @param  : 
* @return : 
*/
int8_t setting_read(void)
{
	static uint32_t nword;
	nword = sizeof(Setting_TypeDef);
	nword = ROUND_UP(sizeof(Setting_TypeDef), 4)>>2;
	
	STMFLASH_Read(SETTINGS_ADDR,(uint32_t*)&setting,nword);
	if(setting.check != FLASH_CHECK)
	{
		setting.check = FLASH_CHECK;
		setting.adc_offset_crg_cur = 0;
		setting.adc_offset_dcrg_cur = 0;
		setting.adc_offset_vol = 0;
		
		STMFLASH_Write(SETTINGS_ADDR,(uint32_t*)&setting,nword);
		return -1;
	}
	return 0;
}


/** 
* @brief  : flash参数保存
* @param  : 
* @param  : 
* @return : 
*/
int8_t setting_write(void)
{
	uint32_t nword = ROUND_UP(sizeof(Setting_TypeDef), 4)>>2;
	setting.check = FLASH_CHECK;
	STMFLASH_Write(SETTINGS_ADDR,(uint32_t*)&setting,nword);
	return 0;
}



/* USER CODE END 0 */

/**
  * @brief  The application entry point.
  * @retval int
  */
int main(void)
{
  /* USER CODE BEGIN 1 */

	uint32_t time_ls=0;
	uint32_t time_50ms=0;
	uint32_t time_bldc=0;
  /* USER CODE END 1 */
  

  /* MCU Configuration--------------------------------------------------------*/

  /* Reset of all peripherals, Initializes the Flash interface and the Systick. */
  HAL_Init();

  /* Configure the system clock */
  SystemClock_Config();

  /* USER CODE BEGIN SysInit */
	MX_GPIO_Init();
	MX_DMA_Init();
	MX_I2C1_Init();
	
	MX_USART1_UART_Init();
	
	NRF24L01_Base_Init();//-- 包含SPI初始化
	while (NRF24L01_Check())
    {
        HAL_Delay(200);
		LL_GPIO_TogglePin(LED_GPIO_Port, LED_Pin);
    }
	RF24L01_Init();
    RF24L01_Set_Mode(MODE_RX);//设置为接收模式
	system.state = SYSTEM_STATE_STANDBY;
	
//	if(__HAL_PWR_GET_FLAG(PWR_FLAG_WU))
//	{
//		uint16_t t=100;
//		LL_GPIO_SetOutputPin(LED_GPIO_Port, LED_Pin);
//		while(1)
//		{
//			delay_us(100);
//			if(0 == --t)
//			{
//				LL_GPIO_ResetOutputPin(LED_GPIO_Port, LED_Pin);
//				if (HAL_RTCEx_SetWakeUpTimer_IT(&hrtc, 3500, RTC_WAKEUPCLOCK_RTCCLK_DIV16) != HAL_OK)
//				  {
//					Error_Handler();
//				  }
//				Sys_Enter_Standby();
//			}
//			if(SYSTEM_STATE_IDLE == system.state)
//			{
//				__HAL_PWR_CLEAR_FLAG(PWR_FLAG_WU);
//				HAL_RTCEx_DeactivateWakeUpTimer(&hrtc);
//				break;
//			}
//		}
//	}
	system.state = SYSTEM_STATE_IDLE;
	
  /* USER CODE END SysInit */

  /* Initialize all configured peripherals */

  /* USER CODE BEGIN 2 */
	
	hrtc.Instance = RTC;
	hrtc.Init.HourFormat = RTC_HOURFORMAT_24;
	hrtc.Init.AsynchPrediv = 127;
	hrtc.Init.SynchPrediv = 255;
	hrtc.Init.OutPut = RTC_OUTPUT_DISABLE;
	hrtc.Init.OutPutRemap = RTC_OUTPUT_REMAP_NONE;
	hrtc.Init.OutPutPolarity = RTC_OUTPUT_POLARITY_HIGH;
	hrtc.Init.OutPutType = RTC_OUTPUT_TYPE_OPENDRAIN;
	if (HAL_RTC_Init(&hrtc) != HAL_OK)
	{
		Error_Handler();
	}
  
	if(0x32F2 != HAL_RTCEx_BKUPRead(&hrtc, RTC_BKP_DR0))
	{
		MX_RTC_Init();
		HAL_RTCEx_BKUPWrite(&hrtc, RTC_BKP_DR0, 0x32F2);
	}
	
//	if(0 > setting_read())
//	{
//		while(1)
//		{
//			HAL_Delay(100);
//			LL_GPIO_TogglePin(LED_GPIO_Port, LED_Pin);
//		}
//	}setting_write();
	control_Init();
	bldc_comm_uart_init();
	MX_ADC_Init();
	
  /* USER CODE END 2 */
 
	uint8_t retry;
	uint32_t t_end;
	
	retry = 5;
	while(retry--)
	{
		bldc_interface_get_fw_version();
		t_end = HAL_GetTick() + 1000;
		while(1)
		{
			bldc_packet_process();
			if((HAL_GetTick() > t_end) || (vesc_info.fw_major>2))
			{
				break;
			}
		}
		if(vesc_info.fw_major>2)
		{
			HAL_Delay(200);
			bldc_interface_get_mcconf();
			t_end = HAL_GetTick() + 1000;
			while(1)
			{
				bldc_packet_process();
				if((HAL_GetTick() > t_end) || (vesc_info.mcconf.l_current_max != 0))
				{
					break;
				}
			}
			break;
		}
		
	}


  /* Infinite loop */
  /* USER CODE BEGIN WHILE */
	while (1)
	{
		bldc_packet_process();

		if(HAL_GetTick()>time_ls)
		{
			time_ls = HAL_GetTick()+1000;
			RTC_Get();
			LL_GPIO_TogglePin(LED_GPIO_Port, LED_Pin);
		}
		
		if(HAL_GetTick() > time_50ms)
		{
			time_50ms = HAL_GetTick()+50;
			HAL_ADC_Start_DMA(&hadc, (uint32_t*)SampleData.ADC_Value_Array, ADC_ARRAY_SIZE);
		}
		
		if(HAL_GetTick() > time_bldc)
		{
			time_bldc = HAL_GetTick()+600;
			if(system.state==SYSTEM_STATE_RUNNING)
			{
				bldc_interface_get_values();
			}
		}
		

    /* USER CODE END WHILE */

    /* USER CODE BEGIN 3 */

	}
  /* USER CODE END 3 */
}

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
/* USER CODE BEGIN 4 */

char error_message[32];

/* USER CODE END 4 */
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


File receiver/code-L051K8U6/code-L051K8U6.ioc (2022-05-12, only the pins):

Mcu.UserName=STM32L051K8Ux
PA0.Signal=S_TIM2_CH1
PA1.Signal=S_TIM2_CH2
PA10.Signal=USART1_RX
PA11.Signal=SPI1_MISO
PA13.Signal=SYS_SWDIO
PA14.Signal=SYS_SWCLK
PA15.Signal=USART2_RX
PA2.Signal=USART2_TX
PA3.Signal=S_TIM2_CH4
PA4.GPIO_Label=NRF_CS
PA4.Signal=GPIO_Output
PA5.Signal=SPI1_SCK
PA6.GPIO_Label=NRF_CE
PA6.Signal=GPIO_Output
PA7.Signal=SPI1_MOSI
PA9.Signal=USART1_TX
PB0.Signal=ADC_IN8
PB1.Signal=ADC_IN9
PB2.GPIO_Label=MPU_INT
PB2.Signal=GPXTI2
PB3.GPIO_Label=NRF_IRQ
PB3.Signal=GPXTI3
PB4.Signal=S_TIM22_CH1
PB5.GPIO_Label=IO_VIN_EN
PB5.Signal=GPIO_Output
PB6.Signal=I2C1_SCL
PB7.Signal=I2C1_SDA
PC14-OSC32_IN.GPIO_Label=LED
PC14-OSC32_IN.Signal=GPIO_Output

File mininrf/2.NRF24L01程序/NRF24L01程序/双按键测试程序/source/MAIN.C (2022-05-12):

/******************************************************************************/
/*                        -- 深圳安信可科技有限公司 --                        */
/*
//  文件名：main.c                                                              
//  说明：供客户测试模块通信使用程序                                                                  
//  编写人员：                                                                   
//  编写日期：                                                              
//  程序维护：
//  维护记录：
//
//                                                          
*/ 
// 免责声明：该程序仅用于学习与交流 
// (c) Anxinke Corporation. All rights reserved.                                                               
/******************************************************************************/
#include "typedef.h"
#include "gpio.h"
#include "uart.h"
#include "nrf24l01p.h"
#include "delay.h"

uchar txData[32] = {0x00};
uchar rxData[32] = {0x00};

/******************************************************************************/
// 函数名称：main 
// 输入参数： 
// 输出参数： 
// 函数功能： 
/******************************************************************************/
void main(void)
{
    unsigned char i=0;
    uartInit();   
    Delay100ms();
    init_nrf24l01_io();
    led1ON();
    Delay100ms();
    led1OFF();
    Delay100ms();
    led1ON();
    Delay100ms();
    led1OFF();
    
    Delay100ms();
    uartSendString("System initialization is complete!\r\n");
    receive_mode_init();
    
    while(1)
    {
        KEY1 = 1;
        KEY2 = 1;
        /*
         * 判断是否按下KEY
        */
        if (key1ON() || key2ON()) {
            _delay_us(500);
            txData[0] = 0;
            if (key1ON()) {
                txData[0] = 0xAA; // 如果按下K1  则将数据置为0xAA  
                uartSendString("You press the left button\r\n"); 
            } else if (key2ON()){
                txData[0] = 0x55; // 如果按下K2  则将数据置为0x55
                uartSendString("You press the Right button\r\n");
            }
            /*
             * 根据不同的数据LED提示
            */
            if (send_data(txData) == 1) {
                uartSendString("Success of sending data\r\n");
                if (txData[0] == 0xAA) {
                    led1ON();    
                } else if (txData[0] == 0x55) {
                    led2ON(); 
                } 
                Delay100ms();   
                led1OFF();
                led2OFF(); 
            } else {
                uartSendString("Failed to send data\r\n");
            }      
            receive_mode_init();
        }
        rxData[0] = 0;
        led1OFF();
        led2OFF();
        if (receive_data(rxData)) {
            if (rxData[0] == 0xAA) {
                led1ON();
                uartSendString("Receiving the data, from the Left\r\n");
            } else if (rxData[0] == 0x55) {
                led2ON();
                uartSendString("Receiving the data, from the Right\r\n");
            }
            Delay100ms();
        }
    
    }
}

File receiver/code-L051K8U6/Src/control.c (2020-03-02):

#include "main.h"
#include "tim.h"
#include "adc.h"
#include "usart.h"
#include "rtc.h"

#include "24l01.h"
#include "control.h"

#include "comm_uart.h"
#include "bldc_interface.h"

#include "crc.h"
#include <string.h>




#define REINIT_TIME  13  //13*10 = 130ms
#define MAX_LOST_TIME 25  //25*10 = 250ms
#define LOST_PD_TIME  1000  //1000*10 = 10s


enum{
	TX_FRAME_1,
	TX_FRAME_2,
	TX_FRAME_MAX,
};

enum{
	RX_FRAME_1,
	RX_FRAME_2,
	RX_FRAME_MAX,
	
};



nRf24l01ModeType NRF_Mode=MODE_RX;   //NRF模块连接模式
static uint8_t nrf_tx_buf[NRF_FIXED_PACKET_LEN],
		nrf_rx_buf[NRF_FIXED_PACKET_LEN];
static uint16_t notfound_time=0;  //丢失信号时间计数器


enum{
	nrf_data_speed,//速度值
	nrf_data_tacho_single,//单次里程
	nrf_data_tacho,//里程
	nrf_data_voltage,//电池电压
	nrf_data_mot_current,//电机电流
	nrf_data_bat_current,//电池电流 <32768表示放电，>32768正表示充电
	nrf_data_board_temp,//板子温度
	nrf_data_wh_drawn,//消耗能量
	nrf_data_wh_regen,//再生能量
	nrf_data_ah_drawn,//消耗能量
	nrf_data_ah_regen,//再生能量
	nrf_data_charge_cur,
	nrf_data_discharge_cur,
	nrf_data_year,
	nrf_data_month,
	nrf_data_day,
	nrf_data_hour,
	nrf_data_min,
	nrf_data_sec,
	
	nrf_data_crc,
	nrf_data_frameid,
	
	nrf_data_throttle,//油门 <1024刹车，>1024给油
	nrf_data_light1,//大灯控制1
	nrf_data_light2,//大灯控制2
	nrf_data_status,//系统状态 0：空闲，1：运行
	
	nrf_data_MAX,
};

static const uint8_t data2bytes[nrf_data_MAX][2]={
	{nrf_data_speed        ,2},
	{nrf_data_tacho_single ,2},
	{nrf_data_tacho        ,4},
	{nrf_data_voltage      ,2},
	{nrf_data_mot_current  ,2},
	{nrf_data_bat_current  ,2},
	{nrf_data_board_temp   ,1},
	{nrf_data_wh_drawn     ,2},
	{nrf_data_wh_regen     ,2},
	{nrf_data_ah_drawn     ,2},
	{nrf_data_ah_regen     ,2},
	{nrf_data_charge_cur   ,2},
	{nrf_data_discharge_cur,2},
	{nrf_data_year         ,1},
	{nrf_data_month        ,1},
	{nrf_data_day          ,1},
	{nrf_data_hour         ,1},
	{nrf_data_min          ,1},
	{nrf_data_sec          ,1},
	
	{nrf_data_crc          ,2},
	{nrf_data_frameid      ,1},
	
	{nrf_data_throttle     ,2},
	{nrf_data_light1       ,2},
	{nrf_data_light2       ,2},
	{nrf_data_status       ,1},
	
};




uint8_t Exue_Control(void);
uint8_t Upload_data(void);


void nrf_int_handler(void)
{
	uint8_t status;
	uint8_t RxLength;
	
	status=NRF24L01_Read_Reg(STATUS);  //读取状态寄存器的值
	NRF24L01_Write_Reg(NRF_WRITE_REG+STATUS,status); //清除TX_DS或MAX_RT中断标志
	if(status&MAX_TX)
	{
		NRF24L01_Write_Reg( FLUSH_TX,0xff );	//清除TX FIFO寄存器
	}
	else if(status&RX_OK)
	{
		RxLength = NRF24L01_Read_Reg( R_RX_PL_WID );		//读取接收到的数据个数
		if(RxLength<=32)
		{
			NRF24L01_Read_Buf( RD_RX_PLOAD,nrf_rx_buf,RxLength );	//接收到数据
			NRF24L01_Write_Reg( FLUSH_RX,0xff );				//清除RX FIFO
			if(Exue_Control()==0)
			{
				notfound_time=0; //接收到数据，清空计数器
				RF24L01_Set_Mode(MODE_TX);
				NRF_Mode=MODE_TX;
			}
		}
	}
	else if(status&TX_OK)
	{
		NRF24L01_Write_Reg( FLUSH_TX,0xff );	//清除TX FIFO寄存器
		notfound_time=0; //发送成功数据，清空计数器
		
		NRF_Mode=MODE_RX;
		RF24L01_Set_Mode(MODE_RX);
	}
}

/**
  * @brief  Period elapsed callback in non-blocking mode
  * @param  htim TIM handle
  * @retval None
  */
void HAL_TIM_PeriodElapsedCallback(TIM_HandleTypeDef *htim)
{
	if(&htim6 == htim)
	{
		if(NRF_Mode == MODE_TX)
		{
			Upload_data();
			NRF24L01_TxPacket(nrf_tx_buf,32);
		}
		else if(NRF_Mode == MODE_RX)
		{
			
		}
		
		if(notfound_time < LOST_PD_TIME)
		{
			notfound_time++;
			if(notfound_time == MAX_LOST_TIME)
			{
				system.state = SYSTEM_STATE_NO_SIGNAL; //计数器满，说明长时间没有信号
				throttle_set(THROTTLE_MAX/2);//立即停止电机
			}
			if(notfound_time == REINIT_TIME)
			{
//				RF24L01_Init();
//				RF24L01_Set_Mode(MODE_RX);//设置为接收模式
			}
		}else
		{
			system.state = SYSTEM_STATE_STANDBY;
		}
	}


}




void AddToArray(uint8_t **pt,uint8_t d_type,uint32_t dat)
{
	uint8_t *p=*pt;
	
	if(1 == data2bytes[d_type][1])
	{
		uint8_t d = dat;
		*p = d;
	}
	else if(2 == data2bytes[d_type][1])
	{
		uint16_t d = dat;
		*p++ = (uint8_t)(d>>8);
		*p++ = (uint8_t)(d&0x00ff);
	}
	else if(4 == data2bytes[d_type][1])
	{
		uint32_t d = dat;
		*p++ = (uint8_t)(d>>24);
		*p++ = (uint8_t)((d&0x00ff0000)>>16);
		*p++ = (uint8_t)((d&0x0000ff00)>>8);
		*p++ = (uint8_t)(d&0x000000ff);
		
	}
	*pt+=data2bytes[d_type][1];
}

uint32_t ParseToData(uint8_t **pt,uint8_t d_type)
{
	uint32_t r;
	uint8_t *p=*pt;
	
	if(1 == data2bytes[d_type][1])
	{
		r = (uint32_t)(*p++);
	}
	else if(2 == data2bytes[d_type][1])
	{
		r  = ((uint32_t)(*p++)<<8);
		r |= ((uint32_t)(*p++));
	}
	else if(4 == data2bytes[d_type][1])
	{
		r  = ((uint32_t)(*p++)<<24);
		r |= ((uint32_t)(*p++)<<16);
		r |= ((uint32_t)(*p++)<<8);
		r |= ((uint32_t)(*p++));
	}
	else r=0;
	
	*pt+=data2bytes[d_type][1];
	return r;
}


//初始化IO口
void control_Init(void)
{
	exit3_callback = nrf_int_handler;
	
	throttle_init();
	light_init();
	bootstrap_init();
	
	MX_TIM6_Init();
	HAL_TIM_Base_Start_IT(&htim6);
	NRF24L01_Write_Reg(NRF_WRITE_REG+STATUS,NRF24L01_Read_Reg(STATUS)); //清除TX_DS或MAX_RT中断标志
	NRF24L01_Write_Reg( FLUSH_RX,0xff );				//清除RX FIFO
	NRF24L01_Write_Reg( FLUSH_TX,0xff );				//清除TX FIFO
	
}




uint8_t Upload_data(void) //更新要上传的数据
{
     uint8_t *ptr = nrf_tx_buf;
	static uint8_t fid=TX_FRAME_1;

	memset(&nrf_tx_buf,0,sizeof(nrf_tx_buf));
	
	ptr+=data2bytes[nrf_data_crc][1];
	AddToArray(&ptr,nrf_data_frameid,fid);
	switch(fid)
	{
		case TX_FRAME_1:
			AddToArray(&ptr,nrf_data_speed        ,SampleData.speed);
			AddToArray(&ptr,nrf_data_tacho_single ,SampleData.tacho_single);
			AddToArray(&ptr,nrf_data_ah_drawn     ,SampleData.ah_drawn);
			AddToArray(&ptr,nrf_data_ah_regen     ,SampleData.ah_regen);
			AddToArray(&ptr,nrf_data_year         ,calendar.w_year);
			AddToArray(&ptr,nrf_data_month        ,calendar.w_month);
			AddToArray(&ptr,nrf_data_day          ,calendar.w_date);
			AddToArray(&ptr,nrf_data_hour         ,calendar.hour);
			AddToArray(&ptr,nrf_data_min          ,calendar.min);
			AddToArray(&ptr,nrf_data_sec          ,calendar.sec);
			fid = TX_FRAME_2;
		break;
		
		case TX_FRAME_2:
			AddToArray(&ptr,nrf_data_voltage      ,SampleData.vin);
			AddToArray(&ptr,nrf_data_bat_current  ,SampleData.bat_current);
			AddToArray(&ptr,nrf_data_mot_current  ,SampleData.mot_current);
			AddToArray(&ptr,nrf_data_board_temp   ,SampleData.board_temp);
			AddToArray(&ptr,nrf_data_charge_cur   ,SampleData.charge_cur);
			AddToArray(&ptr,nrf_data_discharge_cur,SampleData.discharge_cur);
			AddToArray(&ptr,nrf_data_wh_drawn     ,SampleData.wh_drawn);
			AddToArray(&ptr,nrf_data_wh_regen     ,SampleData.wh_regen);
			fid = TX_FRAME_1;
		break;
		default:break;
	}
	
	ptr = nrf_tx_buf;
    AddToArray(&ptr,nrf_data_crc,crc16(nrf_tx_buf+2,sizeof(nrf_tx_buf)-2));//写入接收端校验码
	//AddToArray(&ptr,nrf_data_crc,0x0607);//写入接收端校验码
    return 0;
}
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

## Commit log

2020-03-02 optimize bldc_interface code
2020-03-02 change vin from vesc
2020-03-05 change file structure
    [MOSFET_selector.xlsx]
2020-04-05 add charge page
2022-05-12 add pcb and 3d model
    [Cap.SchLib, CrystalOscillator.SchLib, Diode.SchLib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]

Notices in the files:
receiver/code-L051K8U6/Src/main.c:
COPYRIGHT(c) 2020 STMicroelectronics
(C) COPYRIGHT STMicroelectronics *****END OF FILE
